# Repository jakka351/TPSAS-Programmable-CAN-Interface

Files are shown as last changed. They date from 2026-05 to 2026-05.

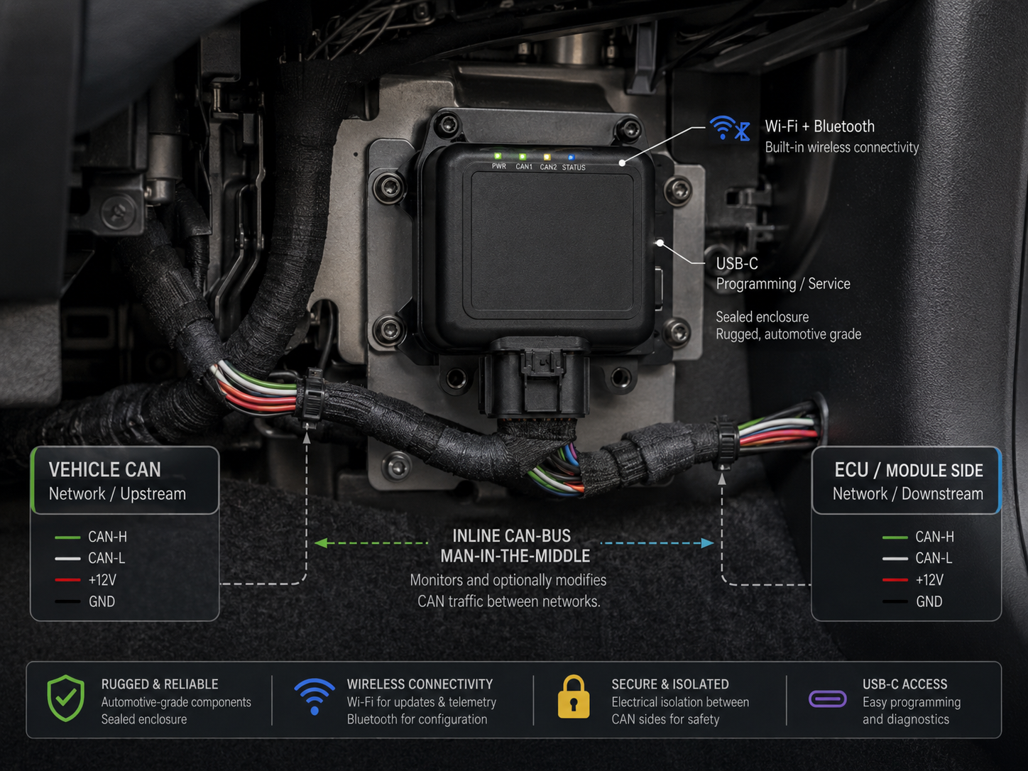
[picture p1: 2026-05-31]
Images/f03ede50-c43b-40d3-97b5-9d50db2d8d2a.png

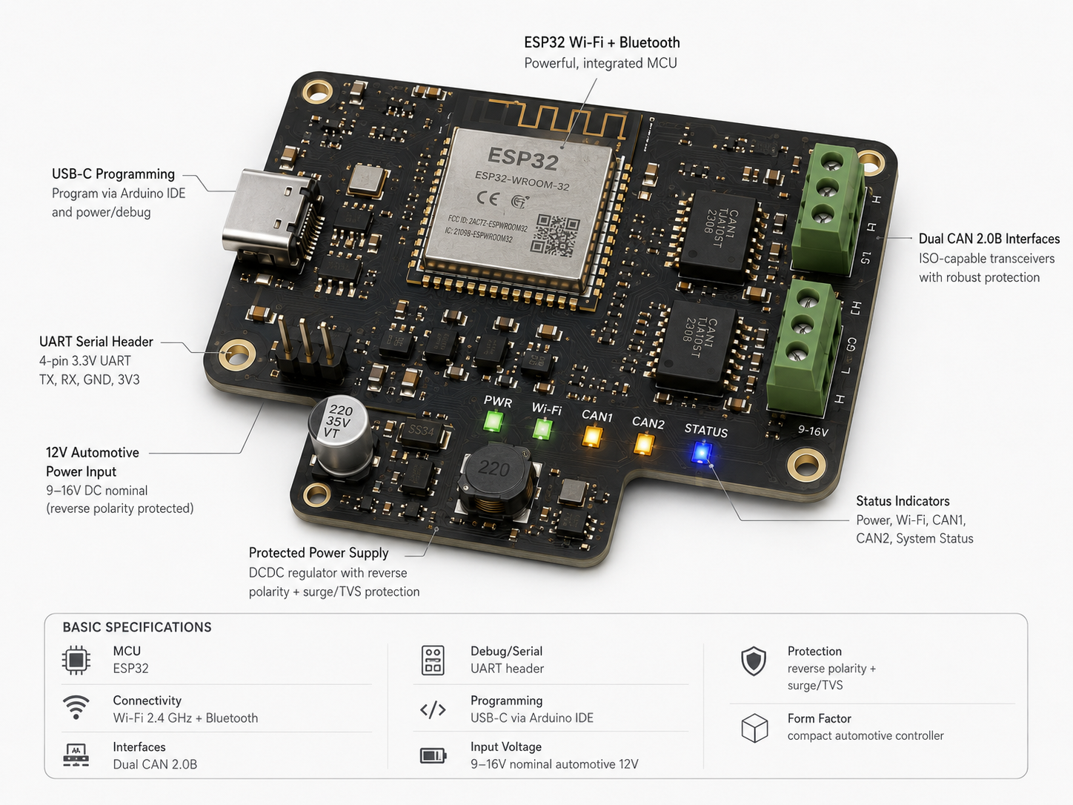
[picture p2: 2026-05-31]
Images/567d3d4d-e929-4fd6-9a81-4a7305392d17.png

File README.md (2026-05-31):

<p align="right"><a href="https://testerpresent.com.au">

</a></p>

# TPSAS-CAN-001
### Tester Present Programmable CAN Interface.


Dual-Isolated CAN Interfaces with Serial UART, Wifi, Bluetooth and USB - Programmable via Arduino IDE or the Tester Present Tool. Available from the releases tab.  

## Firmware Editor and Flash Tool. 
Tester Present developed software for editing firmware, creating a firmware image and flashing it to the device.  
  


## Firmware
Base firmware for the device, to which a customer layer can be added specifying custom behaviour.

***



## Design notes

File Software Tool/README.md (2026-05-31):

<p align="right"><a href="https://testerpresent.com.au">

</a></p>

# TP-CAN-2I Configurator

Windows PC configurator for the **TP-CAN-2I Programmable Dual-CAN Inline Interface**
by *Tester Present Specialist Automotive Solutions*.

It reads, writes, backs up, and flashes the device's firmware/config over **three
transports**, all speaking the same transport-agnostic **TP-DPP v1.0** application
protocol (`Docs/Device_Programming_Protocol.md`):



| Transport | How |
|---|---|
| **J2534 (CAN)** | SAE J2534 PassThru, ISO 15765-2 (ISO-TP) @ 500 kbit/s, tool-TX `0x7FE` / device-RX `0x7FA`. Reuses the existing `J2534` stack. |
| **Serial UART** | COM port @ 921600 8N1, framed `54 50 | LEN(2 BE) | PDU | CRC16-CCITT(2 BE)` with magic resync. |
| **USB-C** | The ESP32-S3 native USB CDC virtual COM port — same serial framing. |

## Features

- **Firmware editor** — IDE-style syntax-highlighting code editor (C/C++/Arduino),
  Consolas font, light theme, line-number gutter, debounced re-highlighting. New /
  Open / Save and a **Build (.bin)** button that shells out to `arduino-cli`.
- **Flash tab** — load a `.bin` or Intel `.hex`, **Read / Backup from device**, and
  **Write + Verify + Activate** with a live progress bar + log, following the §6
  canonical flashing sequence (session → erase → request-download → transfer loop →
  transfer-exit → CRC verify → activate → reset).
- **Console tab** — live transport log + CAN/serial frame traffic.
- **Connection panel** — transport / device (J2534 devices or COM ports) / baud,
  Connect / Disconnect, and a read-only identity readout (app version, serial,
  partition map, running OTA slot).

## Build

Requires the **.NET Framework 4.8.1** targeting pack (the .NET SDK 9 toolchain on
this machine already has it). From the repository root:

```
dotnet build Software/TPCANConfigurator/TPCANConfigurator.csproj -c Release
```

The output `TPCANConfigurator.exe` lands in
`Software/TPCANConfigurator/bin/Release/net481/`.

### Opening in Visual Studio

Open `Software/TPCANConfigurator/TPCANConfigurator.csproj` directly (it's an
SDK-style project). The entire UI is built in code — there is **no** `.Designer.cs`
and **no** `.resx`, so the WinForms designer is intentionally not used (this avoids
designer/resx build pitfalls). Edit `MainForm.cs` and run.

## Project layout

```
TPCANConfigurator/
  TPCANConfigurator.csproj   SDK-style net481 WinForms; includes ..\J2534\**\*.cs
  Program.cs                 [STAThread] entry point
  MainForm.cs                Whole UI (menu, toolbar, panels, tabs, status bar)
  Dpp/
    ITransport.cs            Transport abstraction
    J2534Transport.cs        CAN via J2534Manager (0x7FE/0x7FA)
    SerialTransport.cs       Serial + USB-C (54 50 | LEN | PDU | CRC16 framing)
    DppClient.cs             All TP-DPP services, DIDs, routines, §6 flash flow
    Crc.cs                   CRC-16/CCITT-FALSE + CRC-32/IEEE
  Fw/
    IntelHex.cs              Intel .hex -> byte[]
    FirmwareImage.cs         .bin / .hex loader (bytes + CRC32 + size)
  Editor/
    CodeEditor.cs            RichTextBox + gutter syntax editor
  Compat/
    ELM327Transport.cs       Compile-time stub for a J2534-stack dependency (see note)
```

## Transport notes

- **CAN/J2534**: the adapter does ISO-TP segmentation/reassembly, so the PC side is
  just `J2534Manager.SendReceive(0x7FE, pdu)`. Pick a J2534 device in the Connection
  panel (enumerated from the registry via `J2534DeviceFinder`).
- **Serial / USB-C**: pick a COM port. Baud defaults to 921600 (ignored by USB-CDC,
  honoured by the UART header). The framing layer handles CRC validation and magic
  resync automatically.
- **responsePending (NRC 0x78)**: long operations (erase / write / verify) are
  handled by waiting up to **P2\*** (default 5000 ms, refined from the session
  control response).

## arduino-cli requirement (Build feature)

The editor's **Build (.bin)** button compiles the open sketch by shelling out to
[`arduino-cli`](https://arduino.github.io/arduino-cli/). It is **not bundled**. If it
isn't found on `PATH` (or at the path entered in the *arduino-cli:* box), the app
shows install guidance instead of failing silently:

1. Download `arduino-cli` and put `arduino-cli.exe` on your `PATH`.
2. Install the ESP32 core: `arduino-cli core install esp32:esp32`.
3. Click **Build** — output `.bin` lands in the sketch's `build/` folder
   (`--fqbn esp32:esp32:esp32s3`).

## Note on the J2534 stack

The reused `Software/J2534/*` sources reference an `ELM327Transport` class whose
definition was **not** shipped with those three files. To build without modifying the
read-only J2534 sources, a minimal compile-time stub lives in
`Compat/ELM327Transport.cs`. The Configurator never selects an ELM327 adapter (it
uses J2534 PassThru / Serial / USB-C), so that code path is never exercised.

---

© 2026 Jack Leighton — Designed in Australia

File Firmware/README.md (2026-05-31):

# TP-CAN-2I — ESP32-S3 Firmware (`TesterPresent_CAN_Interface`)

**Tester Present Specialist Automotive Solutions** · © 2026 Jack Leighton · Designed in Australia

Production Arduino firmware for the **TP-CAN-2I Programmable Dual-CAN Inline Interface** — a rugged
automotive CAN man-in-the-middle (MITM) gateway built on the ESP32-S3-WROOM-1-N16R8 with two
galvanically-isolated MCP2518FD CAN-FD channels. It bridges/filters/rewrites CAN traffic between a
vehicle harness (CAN1/upstream) and an ECU/module (CAN2/downstream), and is field-programmable over
**CAN (J2534 ISO-TP)**, **USB-C CDC**, and **UART** using the Tester Present Device Programming
Protocol (TP-DPP), defined in [`../../Docs/Device_Programming_Protocol.md`](../../Docs/Device_Programming_Protocol.md).

---

## 1. Files

| File | Role |
|---|---|
| `TesterPresent_CAN_Interface.ino` | `setup()`/`loop()`: init, MITM bridge, transport→DPP dispatch, LEDs, OTA rollback confirm |
| `config.h` | Pin map, CAN IDs (0x7FE/0x7FA), firmware version + build date, feature flags, default config blob layout |
| `dpp.h` / `dpp.cpp` | Transport-agnostic TP-DPP engine: all services, DIDs, routines, OTA (esp_ota), config blob (NVS), CRC16/CRC32 |
| `isotp.h` / `isotp.cpp` | Minimal ISO 15765-2 (ISO-TP) over one classic-CAN channel (RX 0x7FE / TX 0x7FA) |
| `mcp2518fd.h` / `mcp2518fd.cpp` | Compact self-contained MCP2518FD SPI driver (two instances, shared FSPI bus) |
| `transports.h` / `transports.cpp` | USB-CDC + UART1 `TP`-framing (CRC16-CCITT, magic-resync) + CAN/ISO-TP glue; uniform `getPdu()`/`sendPdu()` |
| `mitm.h` / `mitm.cpp` | CAN1↔CAN2 bridge with per-frame rule hook honouring `mitm_mode` (passthru/filter/rewrite/block) |

---

## 2. GPIO Pin Map (ESP32-S3-WROOM-1-N16R8)

Matches [`../../Hardware/Schematic_Design.md`](../../Hardware/Schematic_Design.md) (Block 6/8) and the
Engineering Specification §5. Strapping-safe choices; the N16R8 octal-PSRAM pins (GPIO26–37) are left
untouched.

| Function | GPIO | Dir | Connected to |
|---|---:|:--:|---|
| USB D− | 19 | — | native USB CDC (fixed by silicon) |
| USB D+ | 20 | — | native USB CDC (fixed by silicon) |
| SPI2/FSPI SCK | 12 | OUT | both MCP2518FD SCK |
| SPI2/FSPI MOSI (SDI) | 11 | OUT | both MCP2518FD SDI |
| SPI2/FSPI MISO (SDO) | 13 | IN | both MCP2518FD SDO |
| CAN1 CS (U7) | 10 | OUT | MCP2518FD #1 nCS (10k pull-up) |
| CAN2 CS (U8) | 14 | OUT | MCP2518FD #2 nCS (10k pull-up) |
| CAN1 INT (U7) | 4 | IN | MCP2518FD #1 nINT (active-low) |
| CAN2 INT (U8) | 5 | IN | MCP2518FD #2 nINT (active-low) |
| UART1 TX | 17 | OUT | DT pin 10 + service header J3 |
| UART1 RX | 18 | IN | DT pin 11 + service header J3 |
| IGN / WAKE sense | 16 | IN | R2/R3 divider off DT pin 3 (RTC-capable) |
| LED Wi-Fi (blue, LED2) | 38 | OUT | → 1k → LED → GND |
| LED CAN1 (amber, LED3) | 39 | OUT | → 1k → LED → GND |
| LED CAN2 (amber, LED4) | 40 | OUT | → 1k → LED → GND |
| LED STATUS (blue, LED5) | 41 | OUT | → 1k → LED → GND |
| LED PWR (green, LED1) | — | — | hard-wired 3V3 → 1k → LED → GND |
| BOOT (SW1) | 0 | IN | strapping; tactile to GND |
| RESET (SW2) | EN | — | chip EN; tactile to GND |

- **SPI:** 10 MHz SCK, MODE0. **Oscillator:** 40 MHz on CLKIN of U7; U7 CLKO daisy-chains U8.
- **Reserved — do not use:** GPIO 26–37 (flash + octal PSRAM). **Avoid as outputs:** 0, 3, 45, 46.

---

## 3. Library Dependencies

The firmware uses **only the Arduino-ESP32 core** — no third-party CAN library is required (the
MCP2518FD driver is self-contained in `mcp2518fd.cpp`). Core components used:

- `SPI` (FSPI bus to the controllers)
- `WiFi` (lightweight SoftAP bring-up; off by default)
- `Preferences` (NVS storage for the config blob + programming-bus select)
- `esp_ota_ops` / `esp_partition` / `esp_system` / `esp_mac` (OTA to the inactive slot, rollback,
  identity) — all bundled with the ESP-IDF inside the Arduino-ESP32 core.

### Install (Arduino IDE — Boards Manager)
1. **File → Preferences → Additional boards manager URLs**, add:
   `https://espressif.github.io/arduino-esp32/package_esp32_index.json`
2. **Tools → Board → Boards Manager…**, install **“esp32” by Espressif Systems** (v3.0.0 or newer,
   which is ESP-IDF v5.x; the OTA/partition API names used here match that line).

### Install (arduino-cli)
```bash
arduino-cli config add board_manager.additional_urls https://espressif.github.io/arduino-esp32/package_esp32_index.json
arduino-cli core update-index
arduino-cli core install esp32:esp32
# Compile (OTA-capable 16 MB partition scheme; see below):
arduino-cli compile --fqbn "esp32:esp32:esp32s3:USBMode=hwcdc,CDCOnBoot=cdc,FlashSize=16M,PartitionScheme=app5M_fat24M_16MB,PSRAM=opi" Firmware/TesterPresent_CAN_Interface
# Upload:
arduino-cli upload -p COMx --fqbn "esp32:esp32:esp32s3:USBMode=hwcdc,CDCOnBoot=cdc,FlashSize=16M,PartitionScheme=app5M_fat24M_16MB,PSRAM=opi" Firmware/TesterPresent_CAN_Interface
```

> Any partition scheme that provides **two app/OTA slots + an NVS partition** works. The default
> `Minimal SPIFFS (1.9MB APP with OTA/190KB SPIFFS)` also has dual OTA but is too small for a 16 MB
> board; prefer a 16 MB OTA layout. If you need a larger single app, generate a custom `partitions.csv`
> with `ota_0`, `ota_1`, `otadata`, and `nvs` and select **“Custom”**.

---

## 4. Arduino IDE Build Settings (Tools menu)

| Setting | Value |
|---|---|
| **Board** | ESP32S3 Dev Module |
| **USB CDC On Boot** | **Enabled** (the configurator + DPP serial transport use the native CDC port) |
| **USB Mode** | Hardware CDC and JTAG |
| **Upload Mode** | UART0 / Hardware CDC |
| **Flash Size** | **16MB (128Mb)** |
| **PSRAM** | OPI PSRAM (N16R8 has 8 MB octal PSRAM) |
| **Partition Scheme** | An **OTA-capable** scheme with **two app slots + NVS** (e.g. *16M Flash (3MB APP/9.9MB FATFS)* or a custom dual-OTA 16 MB CSV) |
| **CPU Frequency** | 240 MHz |
| **Core Debug Level** | None (or Error) |

Manual flashing: hold **BOOT (SW1)**, tap **RST (SW2)**, release BOOT (native USB also supports
auto-reset). After the first successful boot the firmware calls `esp_ota_mark_app_valid_cancel_rollback()`
(~5 s in) so a freshly-flashed OTA image is confirmed and the bootloader will not roll it back.

---

## 5. Feature Flags (`config.h`)

| Macro | Default | Meaning |
|---|---|---|
| `DPP_SECURITY` | `0` | SECURITY_ACCESS (0x27) open: seed = 0, any key accepted. Set `1` for a real seed/key + to gate REQUEST_DOWNLOAD. |
| `CANFD_ENABLE` | `0` | Both channels classic CAN 2.0B @ 500k. Set `1` to honour the config blob’s FD-enable/data-bitrate. |
| `WIFI_ENABLE` | `0` | `0` = radios off (lowest quiescent). `1` = quiet SoftAP `TP-CAN-2I-XXXX` + Wi-Fi LED on. |
| `BLE_ENABLE` | `0` | Reserved for a future field-config build. |

---

## 6. Mapping to the Device Programming Protocol

The byte layouts in `dpp.cpp` follow [`../../Docs/Device_Programming_Protocol.md`](../../Docs/Device_Programming_Protocol.md)
exactly. Quick map:

| TP-DPP item | Where implemented |
|---|---|
| Serial framing `54 50 | LEN | PDU | CRC16` + magic-resync (§2.2/2.3) | `transports.cpp` `sendSerial()` / `pumpSerial()` |
| CAN ISO-TP RX 0x7FE / TX 0x7FA, FRAME_PAD 0xAA (§2.1) | `isotp.cpp` |
| Application PDU + positive/negative responses (§3) | `dpp.cpp` `mkPositive()` / `mkNegative()` |
| Services 0x10/0x11/0x22/0x23/0x27/0x2E/0x31/0x34/0x36/0x37/0x3E (§4) | `dpp.cpp` `svc*()` + `dispatch()` |
| DIDs 0xF180/F181/F18A/F190/F1A0/F1B0/0x0100/0x0103 (§4.1) | `dpp.cpp` `readDidPayload()` / `svcWriteDid()` |
| Routines 0xFF01 erase / 0xFF02 verify / 0xFF03 activate / 0x0202 self-test (§4.2) | `dpp.cpp` `svcRoutine()` |
| NRCs incl. 0x78 responsePending for long ops (§5) | `dpp.cpp` NRC macros + `sendResponsePending()` |
| Flashing sequence 1–9, OTA to inactive slot + CRC32 verify + activate + rollback (§6) | `dpp.cpp` `otaBegin/Write/Finalize/Activate` + `markAppValid()` |
| Timing P2 = 50 ms, P2* = 5000 ms, S3 = 2000 ms (§7) | `config.h` `DPP_P2_MS` / `DPP_P2_STAR_MS` / `DPP_S3_MS` |
| Config blob 35-byte layout + CRC16 (§8) | `config.h` `CFG_OFF_*` + `dpp.cpp` `loadDefaultConfig()` / `validateConfig()` |

**Programming bus.** ISO-TP listens on **CAN1** by default; writing DID `0x0103 = 1` switches it to
**CAN2** at runtime (persisted to NVS, ISO-TP re-bound immediately). The MITM bridge never forwards
the DPP request ID (0x7FE) across the barrier on the active programming bus.

**OTA safety.** Firmware is streamed to the **inactive** OTA slot via `esp_ota_write`, validated at
`esp_ota_end` (no boot change), CRC32-verified by routine 0xFF02 against the image on flash, and only
then made bootable by routine 0xFF03 (`esp_ota_set_boot_partition`). The first boot of a new image runs
in `PENDING_VERIFY`; if it never self-confirms it is rolled back automatically.

---

## 7. Runtime behaviour (LEDs)

| LED | Behaviour |
|---|---|
| PWR (green) | On whenever 3V3 is present (hard-wired). |
| Wi-Fi (blue) | On when SoftAP is up (`WIFI_ENABLE=1`), else off. |
| CAN1 (amber) | Blinks on vehicle-side bus traffic. |
| CAN2 (amber) | Blinks on ECU-side bus traffic. |
| STATUS (blue) | Solid after both controllers init OK; ~1 Hz heartbeat while idle/alive. |

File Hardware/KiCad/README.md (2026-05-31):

# TP-CAN-2I — KiCad Project

This folder is the editable PCB source. Because the board cannot be auto-routed blind, it is
delivered as a **validated 4-layer mechanical starting board** plus the complete electrical
definition needed to finish it in KiCad 7/8.

## Files
| File | What it is |
|---|---|
| `TP-CAN-2I.kicad_pcb` | 4-layer board: enclosure-matched outline, M3 mounting holes, **isolation slots**, stackup, branding, and **labelled placement guides** (Dwgs.User). Generated + self-validated (round-trips through the parser). |
| `TP-CAN-2I.kicad_pro` | Project: design rules, **net classes** (Power / CAN_LOGIC / CAN1_ISO / CAN2_ISO) and net-class auto-assign patterns. |
| `TP-CAN-2I.kicad_dru` | Custom DRC rules enforcing **≥4 mm isolation creepage**. |
| `generate_board.py` | Regenerates the mechanical board (needs `pip install kiutils`). Edit dimensions/placement here. |

## Finish workflow (in KiCad)
1. **Open** `TP-CAN-2I.kicad_pro`. The PCB opens with the outline, holes, slots, and a
   placement guide rectangle + label for every major block (matches `../BOM.csv` ref-des).
2. **Schematic capture:** create `TP-CAN-2I.kicad_sch` and enter the design from
   [`../Schematic_Design.md`](../Schematic_Design.md) (net-by-net, by pin name). Assign each
   symbol the **Footprint** listed in [`../BOM.csv`](../BOM.csv).
3. **Update PCB from schematic** (F8). Components land; drag each onto its labelled guide.
4. **Route** per [`../Fabrication_Notes.md`](../Fabrication_Notes.md):
   ground plane on In1.Cu, power on In2.Cu, CAN pairs coupled, tight buck hot-loop, and
   **nothing crossing the isolation barrier** (the DRC rules will flag violations).
5. **DRC** → fix → **export** Gerbers/drill/CPL to `../Production` (see fab checklist).

## Why it's built this way
KiCad is not installed in the authoring environment, so a hand-routed board could not be
verified. Everything that *can* be made exact and machine-checked — outline, stackup, layers,
mounting, isolation slots, net classes, DRC rules, BOM, and the full net list — is provided
and validated. The remaining step (symbol placement + copper routing) is interactive work that
belongs in KiCad with a human confirming the isolation layout on-screen.

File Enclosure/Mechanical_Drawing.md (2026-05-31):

# TP-CAN-2I — Enclosure Mechanical Drawing

**Model:** TP-CAN-2I Programmable Dual-CAN Inline Interface · **Rev A** · units **mm**
© 2026 Jack Leighton — Tester Present Specialist Automotive Solutions · Designed in Australia

Two-part rugged sealed enclosure (base tray + lid). Manufacturing master is the pair of
2-manifold STL meshes in [`STL/`](STL); this sheet dimensions them for quoting, fixturing and
incoming inspection. Parametric source: [`build_enclosure.py`](build_enclosure.py) (authoritative)
and [`TP-CAN-2I_enclosure.scad`](TP-CAN-2I_enclosure.scad) (OpenSCAD reference).

Previews: [base](STL/preview_base.png) · [lid](STL/preview_lid.png) · [assembly](STL/preview_assembly.png)

---

## 1. Overall envelope

| Dimension | Value |
|---|---|
| Body footprint (excl. ears) | **80.0 × 60.0** |
| Mounting footprint (incl. ears) | **112.4 × 72.8** |
| Base height (floor underside → rim) | **24.6** |
| Lid thickness (plate) | **3.0** |
| Assembled height (ear feet → lid top) | **28.4** |
| Wall thickness | **3.0** |
| Floor / lid thickness | **3.0 / 3.0** |
| Outer vertical corner radius | **4.0** |
| Internal usable cavity (W×D×H) | 74 × 54 × 21.6 |
| Est. printed mass (Tough resin, both parts) | ~95 g |

Coordinate origin = lower-left outer corner of the body, +Z up. The PCB cavity lower-left inner
corner is at (3, 3); the **PCB origin** is (5, 5) and the board is 70 × 50.

---

## 2. Base — top view (looking down −Z)

```
            Y
            ▲   ◄──────────────── 80.0 ────────────────►
            │   ╭───────────────────────────────────────╮
   (-9.2,69.2)●  │  ╭(5.5,54.5)              (74.5,54.5)╮ │  ●(89.2,69.2)
        M5 ⌀5.5  │  ○ tower            LED row →         ○ │   M5 ⌀5.5
            │ ╱  │     ┌───────────────────────────────┐   │ ╲
         60.0    │     │   ◦(9,51)            (71,51)◦  │   │
            │    │     │      PCB standoffs  ⌀6.5       │   │  ┌── connector
            │    │     │      M3 insert ⌀4.0 × 4        │   │  │   aperture
            │    │     │                               │   │  ▼   (on +X wall)
            │    │     │   ◦(9,9)             (71,9)◦   │   │ ████  25.0(Y) × 15.0(Z)
   (-9.2,-9.2)●  │  ○(5.5,5.5)              (74.5,5.5)○ │ │  ●(89.2,-9.2)
        M5 ⌀5.5  │  ╰─────────────────────────────────╯ │   M5 ⌀5.5
            │   ╰────────────────█████────────────────────╯
            │        USB-C port ▲ 13.0(X) × 8.0(Z)  (on −Y wall, ctr X=11)
            └───────────────────────────────────────────────────► X
```

**PCB mounting (M3):** 4 × Ø4.0 heat-set insert pilots at **(9,9) (71,9) (9,51) (71,51)** —
pattern **62 × 42**, standoff Ø6.5 × 4.0 tall (PCB seats at Z=7.0).
**Lid-screw towers (M3):** 4 × Ø4.0 insert pilots at **(5.5,5.5) (74.5,5.5) (5.5,54.5) (74.5,54.5)**,
tops flush with rim (Z=24.6).
**Corner ears (M5):** 4 × Ø5.5 thru with Ø10.0 × 3 deep eyelet pocket; centres at
**(−9.2,−9.2) (89.2,−9.2) (−9.2,69.2) (89.2,69.2)** — pattern **98.4 × 78.4**. Ears drop 0.8 below
the floor to act as defined contact feet.

---

## 3. Base — front view (+X end wall, the connector wall)

```
   Z ▲                         80.0 wide (into page = X is depth here; this is the Y–Z face)
     │   ╭──────────────────────────────────────────╮  ◄ rim (Z=24.6)
24.6 │   │  ░░░ gasket groove 1.2w × 1.4d ░░░░░░░░░░ │
     │   │                                          │
21.0 │   │        ┌────────────────────────┐  ▲     │   connector aperture
     │   │   ⊕    │  Deutsch DT-12 window   │  15.0  │   25.0 (Y) × 15.0 (Z)
13.5 │   │ M3⌀3.3 │  25.0 × 15.0            │  ▼     │   flange screws M3 ⌀3.3
     │   │ flange └────────────────────────┘        │   at Y=14.5 & 45.5, Z=13.5
 6.0 │   │  (Y=14.5)        (Y=45.5)                 │   aperture Y 17.5…42.5
     │   │                                          │
 0.0 │   ╰──────────────────────────────────────────╯  ◄ floor underside
     └──────────────────────────────────────────────► Y
         ◄─────────────────── 60.0 ──────────────────►
```

---

## 4. Base — right side view (−Y wall, the USB wall)

```
   Z ▲          ◄──────────────── 80.0 ────────────────►
24.6 │   ╭───────────────────────────────────────────╮  ◄ rim
     │   │░░ gasket groove ░░░░░░░░░░░░░░░░░░░░░░░░░░░ │
12.6 │   │            ┌───────────┐                   │   USB-C service port
 8.6 │   │   PCB ►----│ 13.0×8.0  │  (ctr X=11)       │   13.0 (X) × 8.0 (Z)
 4.6 │   │            └───────────┘                   │   Z 4.6…12.6  (PCB top Z=8.6)
 0.0 │   ╰───────────────────────────────────────────╯
-0.8 │  ▐█▌                                       ▐█▌    ◄ ear feet protrude 0.8
     └───────────────────────────────────────────────► X
```

---

## 5. Lid (printed upside-down: mating face = Z0)

```
   ╭───────────────────────────────────────────╮   80.0 × 60.0 × 3.0 plate, R4 corners
   │ ⊙(5.5,54.5)                    (74.5,54.5)⊙ │   ⊙ = M3 screw: Ø3.4 thru +
   │                                            │       Ø6.2 × 2 counterbore (from top)
   │            ● ● ● ● ●  LED pipes            │
   │            26 31 36 41 46  (Y=48, Ø3.2)    │   5 × Ø3.2 light-pipe holes @ 5 pitch
   │        ┌────────────────────────┐          │
   │        │  recessed label pocket │          │   branding recess 52 × 14 × 0.6 deep
   │        │  "TESTER PRESENT"      │          │       (engrave / printed insert)
   │        └────────────────────────┘          │
   │ ⊙(5.5,5.5)                      (74.5,5.5)⊙ │
   ╰───────────────────────────────────────────╯
   Underside: 4 perimeter registration ribs (tongue) 2.0 wide × 4.0 deep, set 3.2 in from
   the wall, running the mid-span of each edge (clear of corner towers & standoffs).
```

---

## 6. Seal & closure

| Feature | Spec |
|---|---|
| Seal type | Gasket-in-rim + lid registration tongue |
| Gasket groove | width **1.2**, depth **1.4**, centred in the 3.0 rim (0.9–2.1 from outer edge) |
| Recommended gasket | Ø1.5 mm silicone O-cord (continuous loop), or 1.5 mm closed-cell foam tape |
| Lid tongue | 2.0 × 4.0 ribs, 0.2 clearance to inner wall (registration, not the seal face) |
| Closure | 4 × M3 × 10 SHCS, lid → corner-tower heat-set inserts |
| Sealing target | IP65 (dust-tight, low-pressure water jets) with gasket fitted |

---

## 7. Material, process & tolerances

| Item | Spec |
|---|---|
| Primary process | **SLA**, tough/durable resin (Formlabs Tough 2000 or Durable; or Siraya Tech ABS-Like) |
| Production alt. | **SLS PA12 (nylon)** for highest impact/temperature ruggedness |
| General tolerance | ±0.20 (features), ±0.15 (hole Ø) |
| Heat-set inserts | M3 brass, Ø4.0 pilot (e.g., CNC-Kitchen M3×5.7 / McMaster 94180A331) — install with iron |
| Min wall / detail | 1.5 mm honoured throughout; rim lips 0.9 mm (resin-rigid OK) |
| Finish | bead-blast / matte; UV post-cure per resin spec; black or hi-vis safety orange |
| Print orientation | base: floor-down; lid: top-face-down (mating tongue up) — both supported off feet/ribs |

---

## 8. Inspection checklist (first article)

- [ ] Footprint 80.0 × 60.0 ±0.2; assembled height 28.4 ±0.3.
- [ ] M5 ear pattern 98.4 × 78.4; M5 holes Ø5.5 clear, eyelet pockets Ø10.0 × 3.
- [ ] PCB insert pattern 62 × 42; 4 × Ø4.0 inserts seat flush, PCB datum height 7.0.
- [ ] Connector aperture 25.0 × 15.0 at Z 6–21; flange holes Ø3.3 at Y 14.5/45.5.
- [ ] USB-C port 13.0 × 8.0 at Z 4.6–12.6, centred X=11.
- [ ] 5 × LED Ø3.2 at Y=48, X=26/31/36/41/46.
- [ ] Lid closes on towers; gasket groove clean & continuous; tongue clears towers/standoffs.
- [ ] Watertight check (mesh): lid 2-manifold; base closed solid (see `build_enclosure.py` report).
```

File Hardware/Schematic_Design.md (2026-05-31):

# TP-CAN-2I — Schematic Design (Net-by-Net)

Connections are given by **pin name** (unambiguous for schematic capture). Passive feedback /
timing values are nominal starting points — **confirm against the latest device datasheet**
during schematic finalisation. Reference designators match [`BOM.csv`](BOM.csv).

**Net domains**
- **Logic GND** — ESP32-S3, controllers, regulators, USB.
- **GND_ISO1 / +5V_ISO1** — isolated bus domain for CAN1 (vehicle/upstream).
- **GND_ISO2 / +5V_ISO2** — isolated bus domain for CAN2 (ECU/downstream).
- The three grounds connect **only** through the isolation parts (ISO1042B, A0505S).

---

## Block 1 — Power Input & Protection

```
DT pin1 +VBAT ─► F1(3A) ─► [Q1 N-FET + U11 LM74700 ideal-diode] ─► VBAT_PROT
DT pin2 GND   ─────────────────────────────────────────────────► Logic GND
```
- **F1** in series with +VBAT from connector pin 1.
- **U11 LM74700-Q1** ideal-diode controller drives **Q1 (CSD18532 N-FET)** as reverse-polarity
  pass element: VBAT(fused) → Q1 drain; Q1 source → VBAT_PROT. U11 VS=source, VIN(anode)=drain,
  GATE=Q1 gate, GND=Logic GND. (Blocks reverse current, ~ideal forward drop.)
- **D2 SMCJ33A** TVS: VBAT_PROT → Logic GND (clamps load-dump to ≤53 V).
- **L1 (4.7 µH)** + **C1 (100 µF)** + **C2 (2×10 µF)**: π input filter on VBAT_PROT.

## Block 2 — 5 V Pre-Regulator (U1 TPS54360B-Q1)

| Pin | Net | Notes |
|---|---|---|
| VIN | VBAT_PROT | + C2 bypass |
| EN | VBAT_PROT via R12(499k)/R13(75k) divider | programmable UVLO (~6–7 V on) |
| BOOT | → 100 nF → SW | bootstrap cap |
| SW | → L2(22 µH) → +5V; **D6 SS34** cathode→SW, anode→GND | catch diode (non-sync) |
| FB | +5V via R9(52.3k)/R10(10k) to GND | sets 5.0 V (Vref 0.8 V) |
| RT/CLK | → R11(182k) → GND | ~500 kHz |
| COMP | → R-C compensation → GND | per datasheet (e.g. 3.3 nF + 13 k) |
| GND / PAD | Logic GND | thermal pad to GND pour |

Output **+5V** bulk: **C4 47 µF** + 100 nF. Clamp **D5 SMAJ5.0A** on +5V.

## Block 3 — 3.3 V Logic Regulator (U2 TLV62569)

| Pin (name) | Net |
|---|---|
| VIN | +5V |
| EN | +5V (or GPIO for sequencing) |
| SW | → L3(2.2 µH) → +3V3 |
| FB | +3V3 via R14(540k)/R15(120k) to GND (3.3 V, Vref 0.6 V) |
| GND | Logic GND |

Output **+3V3** bulk: **C5 22 µF** + 100 nF. Powers ESP32-S3, both MCP2518FD (VDD),
ISO1042B **logic side** (VCC1), oscillator, LEDs.

## Block 4 — Isolated CAN Bus Supplies (U3, U4 A0505S-1W)

Two independent modules, each: **+5V → +5V_ISOn**.
- U3: VIN=+5V, GND=Logic GND, VOUT=+5V_ISO1, 0V=GND_ISO1. Bulk **C9 10 µF** on +5V_ISO1.
- U4: VIN=+5V, GND=Logic GND, VOUT=+5V_ISO2, 0V=GND_ISO2. Bulk **C9 10 µF** on +5V_ISO2.
- Input bypass 4.7 µF each. Provides galvanic isolation for each transceiver bus side.

## Block 5 — USB-C Power-Path (U5 LM66100)

- USB **VBUS** → U5 (ideal diode) → +5V rail (OR-ing with buck output so either source powers
  logic on the bench without back-feeding the vehicle supply).
- U5 ON pin tied for auto-on; current-limit per datasheet.

---

## Block 6 — MCU (U6 ESP32-S3-WROOM-1-N16R8)

| Module pin | Net | Notes |
|---|---|---|
| 3V3 | +3V3 | + C10 4.7 µF + 100 nF |
| GND (all) | Logic GND | thermal/RF ground |
| EN | +3V3 via R5(10k); SW2 to GND; 1 µF to GND | reset, RC delay |
| IO0 | R5(10k) to +3V3; SW1 to GND | BOOT strap |
| IO19 | USB_DM | native USB D− |
| IO20 | USB_DP | native USB D+ |
| IO12 | SPI_SCK | to both MCP2518FD SCK |
| IO11 | SPI_MOSI | to both MCP2518FD SDI |
| IO13 | SPI_MISO | from both MCP2518FD SDO |
| IO10 | CAN1_CS | MCP2518FD #1 nCS (R6 10k pull-up to 3V3) |
| IO14 | CAN2_CS | MCP2518FD #2 nCS (R6 10k pull-up to 3V3) |
| IO4 | CAN1_INT | MCP2518FD #1 nINT |
| IO5 | CAN2_INT | MCP2518FD #2 nINT |
| IO17 | UART1_TX | to connector pin10 + service header |
| IO18 | UART1_RX | from connector pin11 + service header |
| IO16 | IGN_SENSE | from divider R2(100k)/R3(22k) off DT pin3 + TVS |
| IO38 | LED_WIFI | → R4(1k) → LED2(blue) → GND |
| IO39 | LED_CAN1 | → R4(1k) → LED3(amber) → GND |
| IO40 | LED_CAN2 | → R4(1k) → LED4(amber) → GND |
| IO41 | LED_STATUS | → R4(1k) → LED5(blue) → GND |
| (3V3) | LED_PWR | +3V3 → R4(1k) → LED1(green) → GND (hard-wired) |

**Reserved (do not connect):** IO26–IO37 (flash + octal PSRAM). Avoid driving IO0/IO3/IO45/IO46.

## Block 7 — USB-C (J1) + ESD (D1)

| J1 | Net |
|---|---|
| VBUS | USB VBUS → U5 power-path |
| GND / SHIELD | Logic GND (shield via RC to GND) |
| CC1 | R1(5.1k) → GND |
| CC2 | R1(5.1k) → GND |
| D+ (both) | → D1 USBLC6 → USB_DP → IO20 |
| D− (both) | → D1 USBLC6 → USB_DM → IO19 |

**D1 USBLC6-2SC6**: I/O1=D+, I/O2=D−, VBUS pin→USB VBUS, GND→GND.

---

## Block 8 — CAN Controllers (U7, U8 MCP2518FD)

Shared SPI bus, independent CS/INT. **Clock:** Y1 40 MHz CMOS oscillator → U7 OSC1; U7
**OSC2/CLKO** → U8 OSC1 (daisy-chain). Each VDD=+3V3 + 100 nF; VSS=Logic GND.

| Signal | U7 (CAN1) | U8 (CAN2) |
|---|---|---|
| nCS | CAN1_CS (IO10) | CAN2_CS (IO14) |
| SCK | SPI_SCK | SPI_SCK |
| SDI | SPI_MOSI | SPI_MOSI |
| SDO | SPI_MISO | SPI_MISO |
| nINT | CAN1_INT (IO4) | CAN2_INT (IO5) |
| OSC1 | Y1 40 MHz | U7 CLKO |
| TXCAN | CAN1_TXD → U9 TXD | CAN2_TXD → U10 TXD |
| RXCAN | CAN1_RXD ← U9 RXD | CAN2_RXD ← U10 RXD |
| VDD/VSS | +3V3 / GND | +3V3 / GND |

## Block 9 — Isolated Transceivers (U9, U10 ISO1042B) + Protection

**U9 = CAN1 (vehicle), U10 = CAN2 (ECU).** Logic side from +3V3/Logic GND; bus side from
+5V_ISOn / GND_ISOn.

| ISO1042B pin | CAN1 (U9) | CAN2 (U10) |
|---|---|---|
| VCC1 (logic) | +3V3 + 100 nF | +3V3 + 100 nF |
| GND1 | Logic GND | Logic GND |
| TXD | CAN1_TXD | CAN2_TXD |
| RXD | CAN1_RXD | CAN2_RXD |
| VCC2 (bus) | +5V_ISO1 + 100 nF + C9 10 µF | +5V_ISO2 + … |
| GND2 | GND_ISO1 | GND_ISO2 |
| CANH | → CMC1 → CAN1H_raw | → CMC2 → CAN2H_raw |
| CANL | → CMC1 → CAN1L_raw | → CMC2 → CAN2L_raw |

**Per-channel bus network (after the common-mode choke CMCn):**
- **Split termination:** R7(60 Ω) CANH→TERMn, R7(60 Ω) TERMn→CANL, **C7 4.7 nF** TERMn→GND_ISOn.
- **Selectable 120 Ω:** R8(120 Ω) across CANH/CANL via jumper J4 (CAN1) / J5 (CAN2).
- **TVS:** D3/D4 **PESD2CAN** CANH/CANL → GND_ISOn.
- CANH/CANL → connector: CAN1→DT pins 4/5, CAN2→DT pins 7/8. GND_ISO1→pin6, GND_ISO2→pin9.

---

## Block 10 — Connectors & Headers

- **J2 Micro-Fit 12-ckt** (internal board header → harness loom): maps 1:1 to the DT 12-way
  pinout in the spec (power, IGN, CAN1 H/L/GND, CAN2 H/L/GND, UART TX/RX/GND).
- **J3 UART service header (1×4):** +3V3, UART1_TX, UART1_RX, Logic GND.
- **J4 / J5:** CAN1 / CAN2 termination select (center = bus, ends = enable 120 Ω / off).

## Block 11 — Ignition / Wake

- DT pin3 (switched +) → R2(100k) → IGN_SENSE node → R3(22k) → GND; TVS to GND; 100 nF.
  IGN_SENSE → ESP32 IO16 (RTC-capable) for deep-sleep wake on ignition.

---

## Net Summary (key)

| Net | Members |
|---|---|
| VBAT_PROT | F1, Q1, U11, D2, L1, C1/C2, U1.VIN |
| +5V | U1 out, U2.VIN, U3.VIN, U4.VIN, U5 out, C4 |
| +3V3 | U2 out, U6.3V3, U7/U8.VDD, U9/U10.VCC1, Y1, LEDs, C5/C10 |
| +5V_ISO1 / GND_ISO1 | U3 out, U9.VCC2/GND2, C9 |
| +5V_ISO2 / GND_ISO2 | U4 out, U10.VCC2/GND2, C9 |
| SPI_SCK/MOSI/MISO | U6 ↔ U7,U8 |
| CAN1_TXD/RXD | U7 ↔ U9 |
| CAN2_TXD/RXD | U8 ↔ U10 |
| CAN1H/L | U9 → CMC1 → term/TVS → DT 4/5 |
| CAN2H/L | U10 → CMC2 → term/TVS → DT 7/8 |

> Isolation barrier runs between {GND1/VCC1/TXD/RXD} and {GND2/VCC2/CANH/CANL} of each
> ISO1042B, and across each A0505S. PCB: route **no** copper across the barrier; mill slots.

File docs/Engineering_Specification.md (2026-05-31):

# Tester Present — Programmable CAN Interface
## Master Engineering Specification

| | |
|---|---|
| **Product** | Programmable Dual-CAN Inline Interface (CAN / Serial / USB / Wireless) |
| **Model** | TP-CAN-2I (Tester Present Specialist Automotive Solutions) |
| **Document** | Master Engineering Specification |
| **Revision** | A (2026-05-31) |
| **Author** | Jack Leighton — Tester Present Specialist Automotive Solutions |
| **Copyright** | © 2026 Jack Leighton. All rights reserved. |
| **Origin** | Designed in Australia |

---

## 1. Product Overview

The TP-CAN-2I is a ruggedised, automotive-grade **inline CAN-bus interface** that installs
between a vehicle harness (upstream) and an ECU/module (downstream). It can **monitor,
pass-through, filter, and optionally rewrite** CAN traffic flowing between the two network
segments — a configurable "man-in-the-middle" for diagnostics, emulation, data-logging,
gateway/translation, and bench development.

It is built around an **ESP32-S3** providing Wi-Fi (telemetry / OTA) and Bluetooth LE
(configuration), with **two fully galvanically-isolated CAN FD channels**, a 3.3 V UART
service port, and native USB-C for programming via the Arduino IDE or the Tester Present
Windows configurator.

### 1.1 Primary Use Cases
- Inline CAN man-in-the-middle (intercept / modify / inject between vehicle and module)
- Dual-bus gateway / protocol translation (CAN-A ↔ CAN-B, different bit-rates)
- High-rate CAN/CAN-FD data logger with wireless off-load
- ECU emulation / residual-bus simulation on a bench
- Field reflash / configuration tool (talks to a target over CAN via J2534)

### 1.2 Design Pillars (from product brief & concept renders)
1. **Rugged & reliable** — automotive-grade components, sealed enclosure, heavy-duty connector.
2. **Wireless** — Wi-Fi for updates & telemetry, Bluetooth LE for configuration.
3. **Secure & isolated** — galvanic isolation between the two CAN sides for safety.
4. **Easy access** — USB-C programming and diagnostics; Arduino-IDE compatible.

---

## 2. Key Specifications

| Parameter | Specification |
|---|---|
| **MCU** | Espressif ESP32-S3-WROOM-1-N16R8 (dual-core LX7 @ 240 MHz, 16 MB flash, 8 MB PSRAM) |
| **Wireless** | Wi-Fi 802.11 b/g/n 2.4 GHz + Bluetooth 5 LE (on-module PCB antenna) |
| **CAN channels** | 2 × independent, **galvanically isolated** CAN FD (ISO 11898-2) |
| **CAN controller** | 2 × Microchip MCP2518FD (external SPI controllers, 40 MHz) |
| **CAN transceiver** | 2 × TI ISO1042B isolated FD transceiver (±70 V bus fault, 5 Mbit/s) |
| **CAN bit-rates** | Classic CAN 2.0B 125 k–1 Mbit/s; CAN FD arbitration ≤1 Mbit/s, data ≤5 Mbit/s |
| **CAN isolation** | ≥3 kV<sub>RMS</sub> channel-to-logic and channel-to-channel (reinforced option 5 kV<sub>RMS</sub>) |
| **Serial** | 1 × 3.3 V UART (TX/RX) on connector + internal service header |
| **USB** | USB-C 2.0 Full-Speed, native (ESP32-S3 USB-OTG), ESD protected |
| **Programming** | (a) USB-C + Arduino IDE; (b) Tester Present app over USB-serial; (c) over CAN via J2534; (d) over UART serial |
| **Input voltage** | **9–32 V DC nominal** (supports both 12 V and 24 V systems); survives load-dump transients (clamped 53 V) |
| **Input protection** | Fuse + reverse-polarity (ideal-diode) + TVS (ISO 7637-2 pulse tolerant) + π-filter |
| **Quiescent / sleep** | < 200 µA in deep-sleep (ignition-wake), typical run ≈ 0.6–1.4 W |
| **Indicators** | 5 × LED: PWR, Wi-Fi, CAN1, CAN2, STATUS |
| **Connector** | Deutsch **DT** series, **12-way**, sealed (IP67-mated), 13 A/contact |
| **Enclosure** | Sealed black SLA/ABS-like, IP65 target, 4 × heavy-duty mounting ears (brass inserts) |
| **Operating temp** | −40 °C … +85 °C (component-rated); enclosure −20 °C … +70 °C |
| **PCB** | 4-layer FR-4, 1.6 mm, ENIG, isolation slots between CAN domains |
| **Dimensions (PCB)** | ≈ 70 × 50 mm (target) |
| **Dimensions (case)** | ≈ 95 × 70 × 32 mm excl. connector & mounting ears |

---

## 3. System Block Diagram

```
                          ┌───────────────────────────────────────────────┐
                          │              TP-CAN-2I  (Logic Domain)         │
                          │                                                │
   USB-C ──[USBLC6 ESD]───┼──► ESP32-S3-WROOM-1-N16R8 ◄── BOOT/RESET btns  │
   (native USB, Arduino)  │      │  │  │  │   (Wi-Fi + BT antenna on module)│
                          │      │  │  │  └── 5× Status LEDs                │
   UART (3v3) ◄───────────┼──────┘  │  └───── UART1 to connector           │
                          │   SPI2  │                                       │
                          │     ┌───┴────┬─────────┐                        │
                          │     ▼        ▼         │                        │
                          │  MCP2518FD MCP2518FD   │  40 MHz osc (CLKO ⮞)   │
                          │   (CAN1)    (CAN2)      │                        │
                          │     │TXD/RXD  │TXD/RXD                          │
   ═══════════ ISOLATION BARRIER ═══════════════════════════════════════   │
                          │     ▼          ▼                                │
                          │  ISO1042B    ISO1042B   ◄── 2× isolated 5V DCDC │
                          │  (iso xcvr)  (iso xcvr)     (A0505S-1W each)     │
                          │  CMC+TVS+    CMC+TVS+                            │
                          │  term       term                                │
                          └───┬───┬──────┬───┬───────────────────────────────┘
                              │   │      │   │
                          CAN1H CAN1L  CAN2H CAN2L
                         (Vehicle/upstream) (ECU/downstream)
                              │   │      │   │
                          ┌───┴───┴──────┴───┴───────────────────────┐
   9–32V ──[Fuse]──[Ideal │  Deutsch DT 12-way heavy-duty connector  │
   diode rev-prot]──[TVS]─┤  + power + ignition/wake + UART          │
            │             └──────────────────────────────────────────┘
            ▼
      TPS54360B-Q1 (Vin→5V/3.5A, 60V) ──► TLV62569 (5V→3.3V/2A) ──► 3V3 logic
            └──► 5V rail ──► 2× isolated DCDC (CAN side) , USB power-path OR
```

---

## 4. Electrical Architecture

### 4.1 Power Tree (12 V / 24 V capable)

| Stage | Part | Function |
|---|---|---|
| Input fuse | 3 A slow-blow (1206 / Nano2) | over-current / fault isolation |
| Reverse-polarity | LM74700-Q1 ideal-diode ctrl + N-FET (CSD18532) | low-loss reverse protection |
| Transient clamp | SMCJ33A TVS (uni) + π-filter (ferrite + bulk caps) | ISO 7637-2 load-dump / surge |
| Pre-regulator | **TPS54360B-Q1** (4.5–60 V in, 3.5 A) → **5.0 V** | wide-Vin buck, survives 24 V load-dump |
| Logic regulator | **TLV62569** (5 V → **3.3 V**, 2 A) | ESP32-S3 + controllers + logic |
| CAN1 bus supply | **A0505S-1W** isolated DCDC (5 V→5 V iso) | ISO1042B VCC2, isolated domain 1 |
| CAN2 bus supply | **A0505S-1W** isolated DCDC (5 V→5 V iso) | ISO1042B VCC2, isolated domain 2 |
| USB power-path | LM66100 ideal diode (USB 5 V ⟶ 5 V rail) | bench-power from USB without back-feed |

**Rail budget (typical):** 3.3 V @ ≤500 mA (ESP32 Wi-Fi bursts) + controllers/LEDs ≈ 150 mA;
5 V rail feeds 2× 1 W isolated converters (≈ 200 mA each in) + USB. Pre-reg sized 3.5 A for margin.

### 4.2 Microcontroller
- **ESP32-S3-WROOM-1-N16R8**: native USB-OTG (no USB-UART bridge required), dual-core,
  16 MB flash / 8 MB PSRAM for large MITM buffers and OTA dual-bank.
- Octal-PSRAM variant occupies GPIO33–37 internally — **those GPIO are reserved, do not use.**
- Antenna keep-out per module datasheet must overhang the PCB edge with no copper beneath.

### 4.3 Dual CAN FD (Isolated)
- Two **MCP2518FD** SPI CAN-FD controllers share **SPI2 (FSPI)** with independent CS + INT.
- One **40 MHz** oscillator clocks controller 1; its **CLKO** output daisy-chains controller 2.
- Each controller's TXD/RXD crosses the isolation barrier through an **ISO1042B** transceiver.
- Each transceiver bus side is powered by its **own isolated 5 V** supply → channel-to-channel
  **and** channel-to-logic galvanic isolation (true MITM safety).
- Bus protection per channel: **common-mode choke** (TDK ACT45B) + **CAN TVS** (PESD2CAN)
  + **split termination** (2 × 60 Ω + 4.7 nF to isolated bus GND) + jumper-selectable 120 Ω.

### 4.4 USB / Programming
- USB-C receptacle (16-pin, with mounting tabs), **CC1/CC2 5.1 kΩ** pull-downs (UFP).
- **USBLC6-2SC6** ESD array on D+/D−.
- Native USB connects to ESP32-S3 GPIO19 (D−) / GPIO20 (D+).
- **BOOT (GPIO0)** + **RESET (EN)** tactiles for manual flashing; auto-reset supported by native USB.

### 4.5 Serial UART
- **UART1** (GPIO17 TX / GPIO18 RX), 3.3 V logic, brought to both the connector and an
  internal 4-pin service header (TX, RX, GND, 3V3).

### 4.6 Status Indicators
| LED | Colour | Driven by | Meaning |
|---|---|---|---|
| PWR | Green | Hard-wired to 3V3 | Power good |
| Wi-Fi | Blue | GPIO38 | Wi-Fi/BT activity |
| CAN1 | Amber | GPIO39 | Vehicle-side bus traffic |
| CAN2 | Amber | GPIO40 | ECU-side bus traffic |
| STATUS | Blue | GPIO41 | System/MITM state (heartbeat/error codes) |

---

## 5. ESP32-S3 Pin Allocation

| Function | GPIO | Notes |
|---|---|---|
| USB D− | 19 | native USB (fixed) |
| USB D+ | 20 | native USB (fixed) |
| SPI2 SCK | 12 | to both MCP2518FD |
| SPI2 MOSI (SDI) | 11 | to both MCP2518FD |
| SPI2 MISO (SDO) | 13 | from both MCP2518FD |
| CAN1 CS | 10 | MCP2518FD #1 chip-select |
| CAN2 CS | 14 | MCP2518FD #2 chip-select |
| CAN1 INT | 4 | MCP2518FD #1 interrupt (input) |
| CAN2 INT | 5 | MCP2518FD #2 interrupt (input) |
| UART1 TX | 17 | 3.3 V serial to connector/header |
| UART1 RX | 18 | 3.3 V serial to connector/header |
| LED Wi-Fi | 38 | |
| LED CAN1 | 39 | |
| LED CAN2 | 40 | |
| LED STATUS | 41 | |
| BOOT | 0 | strapping — tactile to GND |
| Ignition/Wake sense | 16 | via divider+TVS; RTC-capable for deep-sleep wake |
| **Reserved** | 26–37 | SPI flash + **octal PSRAM** (N16R8) — DO NOT USE |
| **Avoid as outputs** | 0, 3, 45, 46 | boot strapping pins |

---

## 6. Heavy-Duty Connector — Deutsch DT 12-Way

External harness connector: **Deutsch DT** series, 12-way, sealed (IP67 mated), 13 A/contact,
14–16 AWG capable. Enclosure-wall flange receptacle → short internal loom → polarised locking
board header (Molex Micro-Fit 3.0, 12-ckt) on the PCB ("ECU-style" serviceable interface).

| Pin | Signal | Domain | Wire (AWG / colour) |
|---|---|---|---|
| 1 | +VBAT (9–32 V power in) | Power | 16 / Red |
| 2 | GND (power / chassis) | Power | 16 / Black |
| 3 | IGN / WAKE (switched +) | Logic | 18 / White |
| 4 | CAN1-H (Vehicle / upstream) | Iso domain 1 | 18 / Yellow (twisted pair) |
| 5 | CAN1-L (Vehicle / upstream) | Iso domain 1 | 18 / Green (twisted pair) |
| 6 | CAN1-GND (vehicle bus ref/shield) | Iso domain 1 | 18 / Bare/Drain |
| 7 | CAN2-H (ECU / downstream) | Iso domain 2 | 18 / Orange (twisted pair) |
| 8 | CAN2-L (ECU / downstream) | Iso domain 2 | 18 / Blue (twisted pair) |
| 9 | CAN2-GND (ECU bus ref/shield) | Iso domain 2 | 18 / Bare/Drain |
| 10 | UART-TX (3.3 V out) | Logic | 22 / Grey |
| 11 | UART-RX (3.3 V in) | Logic | 22 / Violet |
| 12 | UART-GND (logic ref) | Logic | 22 / Brown |

> **Note:** CAN-GND pins (6, 9) reference each isolated transceiver's bus-side ground.
> For a true MITM in a single-chassis vehicle they may be left unterminated or tied to
> local chassis at each node; on a bench they provide the isolated return.

Connector part numbers and the harness build procedure are in
[`/Harness/Connector_and_Harness.md`](../Harness/Connector_and_Harness.md).

---

## 7. Isolation Strategy

- **Logic domain:** ESP32-S3, both MCP2518FD controllers, USB, power regulators, LEDs.
- **Isolated domain 1 (CAN1):** ISO1042B bus side + its isolated 5 V supply.
- **Isolated domain 2 (CAN2):** ISO1042B bus side + its isolated 5 V supply.
- Barrier carried by the ISO1042B reinforced isolation and the isolated DCDC transformers.
- **PCB:** isolation **slots milled** under each ISO1042B and DCDC, ≥ 4 mm creepage logic-to-bus
  and bus-to-bus; no copper, no silkscreen, no traces crossing the barrier except through the
  rated parts. Maintain ≥ 8 mm spacing between the two CAN domains where practical.

---

## 8. Mechanical Envelope

- Two-part sealed enclosure (base + lid) with perimeter **gasket groove** (O-ring cord or
  cured-in-place gasket), IP65 target.
- **4 heavy-duty mounting ears** with **brass heat-set inserts** / steel eyelets for M5 bolts.
- Deutsch DT flange receptacle on one end face; **sealed USB-C service port** (rubber bung)
  on an adjacent face.
- PCB on **4 standoffs/bosses** with M3 brass inserts; 1.5 mm clearance to lid for components.
- **LED light-pipes** (5) through the lid, or a clear window strip.
- Full model + drawing: [`/Enclosure/`](../Enclosure/).

---

## 9. Compliance & Environment (targets)

| Item | Target |
|---|---|
| Conducted transients | ISO 7637-2 pulses 1, 2a, 2b, 3a, 3b (clamped front-end) |
| Supply ranges | ISO 16750-2 (12 V & 24 V systems), load-dump survival |
| ESD | IEC 61000-4-2 ±8 kV contact on exposed I/O & USB |
| CAN PHY | ISO 11898-2:2016 (CAN FD) |
| Ingress | IP65 (enclosure), IP67 (mated connector) |
| RoHS / REACH | Compliant component selection |

---

## 10. Programming & Configuration Interfaces

| Path | Transport | Use | Tool |
|---|---|---|---|
| Firmware flash | USB-C native | Load/replace firmware | **Arduino IDE** (ESP32-S3 board) |
| Firmware flash | USB-C native | Load/replace firmware | Tester Present app (esptool backend) |
| Configuration | USB-serial (CDC) | Set CAN bit-rates, MITM rules, filters, Wi-Fi creds | Tester Present app |
| Configuration | **CAN via J2534** | Program/config over the bus | Tester Present app (J2534 PassThru) |
| Configuration | UART serial | Headless config | Tester Present app / terminal |
| Live / OTA | Wi-Fi | Telemetry, OTA update | Tester Present app / web |
| Config | Bluetooth LE | Mobile/field config | (future) |

The on-the-wire configuration protocol is defined in the firmware and mirrored by the
Windows app — see [`/Firmware`](../Firmware/) and [`/Software`](../Software/).

---

## 11. Deliverables Map

| Folder | Contents |
|---|---|
| `/Docs` | This spec, datasheet, design notes |
| `/Hardware/KiCad` | KiCad project (schematic, PCB, netlist) |
| `/Hardware` | `BOM.csv`, fabrication notes |
| `/Enclosure` | OpenSCAD case (base + lid), STL output, drawing |
| `/Harness` | Deutsch DT pinout + harness build document |
| `/Firmware` | ESP32-S3 Arduino firmware |
| `/Software` | .NET 4.8.1 WinForms configurator (J2534 + serial) |

---
*Tester Present Specialist Automotive Solutions — Designed in Australia — © 2026 Jack Leighton.*

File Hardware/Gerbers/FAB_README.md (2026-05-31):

# TP-CAN-2I - Fabrication Gerber Package (REAL COPPER)

Generated by `generate_pcb.py`. Unlike the earlier mechanical-only set, these
layers contain **real copper**: every component land pattern is flashed, the
four copper layers carry pours/planes and routing, solder mask and paste are
matched to the pads, and the drill files are populated.

## Board
| Parameter | Value |
|---|---|
| Size | 70.0 x 50.0 mm, R3 corners |
| Layers | 4 (Sig / GND / PWR / GND) |
| Thickness | 1.6 mm, FR-4 Tg>=150 |
| Copper | 1 oz outer / 0.5 oz inner |
| Finish | ENIG |
| Mask / Silk | Matte black / white |
| Min track/gap | 0.25 / 0.20 mm |
| Via | 0.3 mm drill / 0.6 mm pad |

## What is in this package
- **F_Cu**: 423 flashes - SMD + THT land patterns, via lands, and routed
  power tree, SPI2 bus, CAN TXD/RXD, isolated CAN_H/CAN_L pairs, USB pair, UART.
- **In1_Cu (GND)** and **B_Cu (GND)**: split into three galvanically isolated
  ground domains - LOGIC | CAN1-ISO | CAN2-ISO - with the pours pulled back
  >4 mm around the x=54 mm barrier and the two milled isolation slots.
- **In2_Cu (PWR)**: +3V3 / +5V logic rails plus the two isolated +5V_ISO pours.
  Antipad clearances are punched around every non-matching drilled hole; matching
  power/ground holes connect directly to their plane.
- **F_Mask / B_Mask / F_Paste**: openings/stencil for all pads (vias tented).
- **Edge_Cuts**: outline + the two isolation milling slots under U9/U10.
- **PTH.drl (117 holes)** and **NPTH.drl (4x M3 Ø3.2)**.

## Isolation (spec section 7)
The two CAN channels are separated from the logic domain and from each other.
The ISO1042B transceivers and A0505S isolated DCDC converters are the only parts
that bridge the barrier; no plane copper crosses the slot/barrier gap.

## IMPORTANT - review before production
This is a programmatically generated physical layout: land patterns, pours,
vias, mask, paste and drill are real and self-consistent. Pad-to-pin **net
assignment follows the engineering spec's pin map but MUST be cross-checked
against the schematic/netlist** (IPC-356) before committing to fabrication, and
a Gerber viewer (KiCad / Gerbv / the fab's online viewer) should be used to
confirm clearances and the isolation gap for your chosen creepage rating.

Components: 92 placements, 45 routed segments.

---
Tester Present Specialist Automotive Solutions - Designed in Australia - (c) 2026 Jack Leighton.

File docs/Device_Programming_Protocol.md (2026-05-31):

# TP-CAN-2I — Device Programming Protocol (TP-DPP) v1.0

**Tester Present Specialist Automotive Solutions** · © 2026 Jack Leighton · Designed in Australia

This is the **single source of truth** for how the PC software and the device firmware talk to
each other for **reading, writing, and flashing firmware/config**. The firmware (ESP32-S3) and the
.NET 4.8.1 configurator MUST both implement this document exactly. It is transport-agnostic: the
same Application PDU rides over **CAN (via J2534 ISO-TP)**, **Serial UART**, and **USB-C CDC**.

---

## 1. Design goals

- **One command set, three transports.** Identical request/response PDUs on CAN, UART, USB-C.
- **J2534-native.** The CAN transport is ISO 15765-2 (ISO-TP), which every J2534 PassThru driver
  segments/reassembles for free — so the PC side is just `J2534Manager.SendReceive(0x7FE, pdu)`.
- **UDS-flavoured.** Service IDs mirror a subset of ISO 14229 (UDS) so the flow is familiar and
  tooling-friendly, but the ID space (0x7FE/0x7FA), DIDs, and routines are our own.
- **Safe field updates.** Firmware is written to the **inactive OTA slot**, CRC-verified, then
  activated on the next reset. A bad image never bricks the unit (rolls back to the known-good slot).

---

## 2. Transport layer

### 2.1 CAN (J2534 / ISO 15765-2)
| Item | Value |
|---|---|
| Bus | 500 kbit/s classic CAN 2.0B, 11-bit IDs |
| **Request ID (PC → device)** | **0x7FE** (PC *transmits* on 0x7FE) |
| **Response ID (device → PC)** | **0x7FA** (PC *receives* on 0x7FA) |
| Addressing | ISO-TP normal addressing, FRAME_PAD (pad to 8 bytes, 0xAA) |
| Max PDU | 4095 bytes (ISO-TP limit); we cap blocks well under this (§6) |
| Which bus | Firmware listens for 0x7FE on **CAN1 (vehicle/upstream)** by default; also
selectable on CAN2 via config DID `0x0103`. |

> From the PC's point of view this is exactly **"RX 0x7FA / TX 0x7FE"**. On the J2534 side, open
> ISO15765 @ 500k and install a flow-control filter with `txId=0x7FE, rxId=0x7FA`, then use the
> existing `J2534Manager.SendReceive(0x7FE, pdu)` — ISO-TP multiframe is handled by the adapter.

### 2.2 Serial UART  &  2.3 USB-C CDC
Both use the **same framing** (USB-C is the ESP32-S3 native USB CDC virtual COM port; UART is the
harness service lines pins 10/11/12 or service header J3).

| Item | Value |
|---|---|
| UART baud | 921600, 8N1, no flow control (USB-CDC baud is irrelevant/ignored) |
| Frame | `MAGIC(2) | LEN(2) | PDU(LEN) | CRC16(2)` |
| MAGIC | `0x54 0x50` (`"TP"`) |
| LEN | big-endian, length of PDU only (0…4095) |
| CRC16 | CRC-16/CCITT-FALSE (poly 0x1021, init 0xFFFF), big-endian, computed over **MAGIC+LEN+PDU** |
| Resync | On CRC mismatch the receiver slides forward one byte and re-scans for MAGIC. |

No byte-stuffing is used; the length + CRC + magic resync keep the stream self-correcting.

---

## 3. Application PDU (transport-agnostic)

```
Request : [ SID ] [ param bytes … ]
Positive: [ SID + 0x40 ] [ data bytes … ]
Negative: [ 0x7F ] [ SID ] [ NRC ]
```

Multi-byte fields are **big-endian**. The PDU is the payload of the CAN ISO-TP message *or* the
`PDU` field of a serial frame — never both wrapped together.

---

## 4. Service catalog

| SID | Name | Request params | Positive response |
|---|---|---|---|
| 0x10 | SESSION_CONTROL | `subfn` (01=default, 02=programming) | `subfn` + `P2(2)` + `P2*(2)` ms |
| 0x11 | ECU_RESET | `subfn` (01=hardReset, 03=jumpToApp) | `subfn` |
| 0x27 | SECURITY_ACCESS | `01`=requestSeed → / `02`=sendKey+key(4) | seed(4) / (empty) |
| 0x3E | TESTER_PRESENT | `00` | `00` |
| 0x22 | READ_DATA_BY_ID | `DID(2)` | `DID(2)` + data |
| 0x2E | WRITE_DATA_BY_ID | `DID(2)` + data | `DID(2)` |
| 0x23 | READ_MEMORY | `addr(4)` + `len(2)` | data (`len` bytes, len ≤ 1024) |
| 0x31 | ROUTINE_CONTROL | `01`=start `routineId(2)` [+opt] | `01` + `routineId(2)` + `status(1)` [+result] |
| 0x34 | REQUEST_DOWNLOAD | `fmt(1)` `alfid(1)` `addr(4)` `size(4)` `crc32(4)` | `lenFmt(1)` + `maxBlock(2)` |
| 0x36 | TRANSFER_DATA | `bsc(1)` + data | `bsc(1)` |
| 0x37 | REQUEST_TRANSFER_EXIT | (none) | `status(1)` |

`SECURITY_ACCESS` is **optional** (compile flag `DPP_SECURITY`). Default bench build is open
(seed returns 0, any key accepted) so it never blocks development; production may enable a real
seed/key. `fmt`/`alfid` follow UDS convention; for us `fmt=0x00`, `alfid=0x44` (4-byte addr + 4-byte size).

### 4.1 Data Identifiers (DIDs, for 0x22 / 0x2E)
| DID | R/W | Meaning |
|---|---|---|
| 0xF180 | R | Bootloader/protocol version (ASCII, e.g. `TP-DPP 1.0`) |
| 0xF181 | R | Application firmware version (ASCII semver + build date) |
| 0xF18A | R | Device serial number (12 bytes) |
| 0xF190 | R | Chip ID / Wi-Fi MAC (6 bytes) |
| 0xF1A0 | R | Partition map: `running(1) slotA_size(4) slotB_size(4) appUsed(4)` |
| 0xF1B0 | R | Active/running OTA slot (0 or 1) |
| 0x0100 | R/W | Device config blob (CAN bitrates, MITM mode, name) — see §8 |
| 0x0103 | R/W | Programming-bus select: 0=CAN1, 1=CAN2 |

### 4.2 Routines (for 0x31, sub 0x01 = startRoutine)
| routineId | Meaning | Extra req | status |
|---|---|---|---|
| 0xFF01 | Erase inactive OTA slot | — | 0x00 ok / 0x01 busy / 0x02 fail |
| 0xFF02 | Verify staged image CRC32 | `crc32(4)` (expected) | 0x00 match / 0x03 mismatch |
| 0xFF03 | Activate staged image (set boot + mark valid) | — | 0x00 ok |
| 0x0202 | Self-test (CAN1/CAN2 loopback, isolation rails) | — | bitmask result(1) |

---

## 5. Negative Response Codes (NRC)
| NRC | Meaning |
|---|---|
| 0x10 | generalReject |
| 0x11 | serviceNotSupported |
| 0x13 | incorrectMessageLengthOrInvalidFormat |
| 0x22 | conditionsNotCorrect (e.g. not in programming session) |
| 0x24 | requestSequenceError (e.g. TRANSFER_DATA before REQUEST_DOWNLOAD) |
| 0x31 | requestOutOfRange (addr/len/DID) |
| 0x35 | invalidKey (security) |
| 0x72 | programmingFailure (flash write/erase error) |
| 0x73 | wrongBlockSequenceCounter |
| 0x78 | responsePending (firmware busy; PC waits up to P2*) |

---

## 6. Canonical flashing sequence (write/update firmware)

The PC turns a firmware image (`.bin`, or `.hex`→bin) into this exchange:

1. `10 02` — enter **programming session** (resp gives P2/P2* timing).
2. `27 01` → seed; `27 02 <key>` — security (no-op on open builds).
3. `31 01 FF01` — **erase** inactive OTA slot (firmware replies `78` responsePending then `00`).
4. `34 00 44 <addr=00000000> <size> <crc32>` — **request download**; device replies `maxBlock`
   (e.g. 0x0200 = 512). `addr=0` means "the inactive OTA slot".
5. Loop **`36 <bsc> <chunk>`** with `chunk ≤ maxBlock`, `bsc` = 1,2,3…wrapping 0xFF→0x00. Device
   echoes `bsc`. (Firmware streams each chunk straight into `esp_ota_write`.)
6. `37` — **request transfer exit** (device finalises the OTA write).
7. `31 01 FF02 <crc32>` — **verify** staged image CRC32 (must match what was sent in step 4).
8. `31 01 FF03` — **activate** (set boot partition, mark OTA valid).
9. `11 01` — **hard reset**; unit reboots into the new image. If the new image fails to confirm
   itself healthy, the ESP32 rolls back to the previous slot automatically.

Progress % = bytes sent / total size. PC keeps the session alive with `3E 00` if a step approaches P2*.

## 6b. Reading firmware / config

- **Read identity:** `22 F181` (app version), `22 F18A` (serial), `22 F1A0` (partition map).
- **Read memory/flash region:** `23 <addr(4)> <len(2)>` in ≤1024-byte windows; PC concatenates.
  (Used to dump the running app slot for backup before an update.)
- **Read config:** `22 0100`; **write config:** `2E 0100 <blob>` (no reflash needed).

---

## 7. Timing
| Param | Value | Use |
|---|---|---|
| P2 | 50 ms | normal request→response |
| P2* | 5000 ms | extended (erase/write/verify), signalled by NRC 0x78 |
| S3 (tester present) | send `3E 00` every 2000 ms while a programming session is open |
| Inter-block | none required; device flow-controls via ISO-TP / serial CRC-NAK |

---

## 8. Device config blob (DID 0x0100) layout
```
offset  size  field
0       1     version (=1)
1       1     mitm_mode      0=passthru 1=filter 2=rewrite 3=block
2       4     can1_bitrate   (bit/s, e.g. 500000)
6       4     can2_bitrate
10      1     can_fd_enable  bit0=CAN1 FD, bit1=CAN2 FD
11      4     can_fd_data_bitrate
15      1     term1_enable   on-board 120R CAN1 (0/1)
16      1     term2_enable   on-board 120R CAN2 (0/1)
17      16    device_name    ASCII, null-padded
33      2     crc16          CRC-16/CCITT over bytes 0..32
```

---

## 9. Worked examples

**CAN (bytes on the wire are ISO-TP-segmented by the adapter; PDUs shown logically):**
```
PC → 0x7FE : 10 02                      enter programming session
dev→ 0x7FA : 50 02 00 32 13 88          P2=50ms P2*=5000ms
PC → 0x7FE : 34 00 44 00 00 00 00 00 01 00 00 1A 2B 3C 4D   download 64 KiB, crc 0x1A2B3C4D
dev→ 0x7FA : 74 02 02 00                 maxBlock = 0x0200 (512)
PC → 0x7FE : 36 01 <512 bytes>          first block
dev→ 0x7FA : 76 01
...                                      (repeat, bsc++)
PC → 0x7FE : 37                          transfer exit
dev→ 0x7FA : 77 00
PC → 0x7FE : 31 01 FF02 1A 2B 3C 4D      verify crc
dev→ 0x7FA : 71 01 FF02 00               match
PC → 0x7FE : 31 01 FF03                  activate
dev→ 0x7FA : 71 01 FF03 00
PC → 0x7FE : 11 01                       reset → boots new image
dev→ 0x7FA : 51 01
```

**Serial/USB-CDC** wraps each identical PDU as `54 50 | LEN | PDU | CRC16`. Example `3E 00`:
```
54 50 00 02 3E 00 <crc16>
```

---

## 10. Versioning
The protocol version is read via `22 F180`. Minor additions (new DIDs/routines) keep `1.x`;
breaking changes bump the major. Firmware and PC software both advertise their supported version
in their About/identity strings.
```

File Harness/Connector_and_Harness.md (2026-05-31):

# TP-CAN-2I — Heavy-Duty Connector & Wiring Harness

**Model:** TP-CAN-2I Programmable Dual-CAN Inline Interface · **Rev A**
© 2026 Jack Leighton — Tester Present Specialist Automotive Solutions · Designed in Australia

This document specifies the sealed automotive connector on the device, the internal board
interface, the device-side service harness, and the recommended in-vehicle (inline / pass-through)
deployment. It is written so a harness shop can build it and an installer can fit it.

---

## 1. Connector System Overview

The device presents **one sealed 12-way Deutsch DT receptacle** on the +X end wall. A single
mating plug carries everything the device needs: wide-range power, ignition sense, **both isolated
CAN buses**, and the **UART service link**.

```
            DEVICE (sealed enclosure)                         FIELD HARNESS
   ┌───────────────────────────────────┐
   │  PCB                               │        DT04-12PA            DT06-12SA
   │  ┌──────────┐   internal pigtail   │        receptacle          plug (mates)
   │  │ J2 Molex │ 12× size-16  ┌───────┴──┐    (pins, device)      (sockets, harness)
   │  │ Micro-Fit│══════════════│ bulkhead │◄════════╗
   │  │ 3.0 12ck │   150 mm      │ DT recep │         ║  ──► Power branch (FUSED)
   │  └──────────┘              └───────┬──┘         ║  ──► Vehicle branch  (CAN1)
   │                                    │            ║  ──► ECU branch      (CAN2)
   └───────────────────────────────────┘            ║  ──► UART service pigtail
                                                  trunk ~300 mm
```

Two-stage interface — **the same approach a production ECU uses**:

| Stage | Part | Why |
|---|---|---|
| **External** (case wall ↔ field harness) | Deutsch **DT 12-way**, sealed IP67 | Rugged, vibration-proof, glove-friendly, industry standard for off-road/truck/marine |
| **Internal** (case wall ↔ PCB) | Molex **Micro-Fit 3.0 12-ckt** + short pigtail | Lets the lid/PCB be serviced without disturbing the sealed bulkhead; polarised, latched |

> The DT family is a *wire-to-wire* system; it has no PCB-mount variant by design. Bridging it to
> the board with a short internal pigtail to a Micro-Fit header is the correct, field-proven pattern
> and keeps the IP67 bulkhead seal independent of board service.

---

## 2. Device-Side Connector — Deutsch DT 12-Way (Bill of Material)

All parts TE Connectivity / Deutsch. Quantities are **per device** unless noted.

| Item | TE / Deutsch P/N | Qty | Notes |
|---|---|---|---|
| Receptacle, 12-way, **A**-key (holds **pins**) | **DT04-12PA** | 1 | Mounts in case wall; device side |
| Wedgelock for receptacle | **W12P** | 1 | Secondary lock for DT04-12PA |
| Solid **pin** contacts, size 16 (nickel) | **0460-202-16141** | 12 | 16–20 AWG, 13 A; gold = 0460-202-1631 |
| Cavity sealing plugs (size 16) | **0413-204-1605** | as needed | Fill any unused cavity to keep IP67 |
| **Mating** plug, 12-way, A-key (holds **sockets**) | **DT06-12SA** | 1 | Harness side |
| Wedgelock for plug | **W12S** | 1 | Secondary lock for DT06-12SA |
| Solid **socket** contacts, size 16 (nickel) | **0462-201-16141** | 12 | 16–20 AWG; gold = 0462-201-1631 |

**Tooling**
- Crimp (size-16 solid contacts): Deutsch **HDT-48-00** hand crimper (or equivalent 4-indent).
- Contact removal: size-16 release tool **0411-336-1605**.
- Wedgelock seating: by hand until it clicks; never force past the lock tabs.

**Keying.** Both halves specified **A-key** so the harness can only seat one way and will not
mate with another DT-12 on the vehicle. If the same vehicle already runs DT-12 connectors, order
the device with **B** or **C** key (factory option) to prevent cross-mating.

---

## 3. Bulkhead Mounting (case wall)

The enclosure (`/Enclosure/TP-CAN-2I_enclosure.scad`) provides the matching cutout and bolt
pattern on the +X wall:

- Aperture: **25.0 mm (Y) × 21.0 mm (Z)**, lower edge **+6 mm above the inner floor**.
- Two flange screws: **M3, 31.0 mm spacing (Y)**, centred on the aperture.

Retain the DT04-12PA by clamping its rear shoulder to the inside wall with a **1.5 mm stainless
retention plate** (laser-cut, bolt pattern above) — this is a fabricated part the case shop makes
from the enclosure drawing. The receptacle's integral interfacial seal + the wall face give the
IP67 line; add a thin smear of dielectric grease on the seal at assembly. (TE's snap-in panel
clip may be substituted if the wall is left at nominal 3 mm.)

---

## 4. Internal Board Interface — Molex Micro-Fit 3.0 (12-circuit)

| Item | Molex P/N | Qty | Notes |
|---|---|---|---|
| PCB header, dual-row 12-ckt, 3.00 mm | **0430451200** (43045-1200) | 1 | Ref **J2**, on PCB |
| Crimp receptacle housing, 12-ckt | **0430251200** (43025-1200) | 1 | On internal pigtail |
| Female crimp terminals (20–24 AWG) | **0430300007** (43030-0007) | 12 | Gold; tin = 43030-0001 |

**Internal pigtail.** 12 leads, **150 mm**, size-16 *solid pin* contacts on the bulkhead end
(into DT04-12PA) and Micro-Fit terminals on the J2 end. Use **20 AWG TXL** for all 12 internal
leads (fits both contact systems; the run is short so power loss is negligible). Dress the pigtail
with a service loop so the lid lifts ~40 mm without strain.

---

## 5. Master Pinout (12-way) — applies to DT, the pigtail, and J2

Pin numbering follows the **DT04-12PA cavity map** (stamped on the receptacle face). The internal
pigtail maps DT cavity *n* → J2 pin *n* one-to-one.

| Pin | Signal | Domain | Direction | Wire (field harness) | Colour |
|---:|---|---|---|---|---|
| 1 | **+VBAT** (9–32 V) | Power | IN | 16 AWG | Red |
| 2 | **GND** (power return) | Power | — | 16 AWG | Black |
| 3 | **IGN / WAKE** (switched +12 V sense) | Power | IN | 20 AWG | Pink |
| 4 | **CAN1_H** (vehicle bus) | CAN1 ISO | bidir | 18 AWG, twisted w/ 5 | Yellow |
| 5 | **CAN1_L** (vehicle bus) | CAN1 ISO | bidir | 18 AWG, twisted w/ 4 | Green |
| 6 | **CAN1_GND / shield** | CAN1 ISO | — | 20 AWG drain | Bare/Blk-Wht |
| 7 | **CAN2_H** (ECU bus) | CAN2 ISO | bidir | 18 AWG, twisted w/ 8 | Wht/Yellow |
| 8 | **CAN2_L** (ECU bus) | CAN2 ISO | bidir | 18 AWG, twisted w/ 7 | Wht/Green |
| 9 | **CAN2_GND / shield** | CAN2 ISO | — | 20 AWG drain | Bare/Blk-Wht |
| 10 | **UART_TX** (device → host) | Logic | OUT | 20 AWG | Blue |
| 11 | **UART_RX** (host → device) | Logic | IN | 20 AWG | Orange |
| 12 | **UART_GND** | Logic | — | 20 AWG | Brown |

> **Isolation note.** Pins 4–6 (CAN1) and 7–9 (CAN2) are **galvanically isolated** from each other
> and from logic/power inside the device. *Do not bond* CAN1_GND, CAN2_GND, UART_GND, or power GND
> together anywhere in the harness — each ground stays with its own twisted set. Joining them
> defeats the isolation barrier that protects the vehicle and ECU.

---

## 6. Wire Specification

- **Power (1,2):** 16 AWG TXL/GXL automotive, 105 °C. Carries device draw (≤0.6 A typ.) plus margin.
- **Ignition (3):** 20 AWG TXL. High-impedance sense input; current is negligible.
- **CAN pairs (4/5, 7/8):** 18 AWG, **120 Ω shielded twisted pair**, ~33–40 twists/m. Keep each pair
  twisted to within 30 mm of the contact. Drain wire (6, 9) bonded to the foil shield **at the
  device end only** (avoid ground loops).
- **UART (10,11,12):** 20 AWG; run as a loose triad. Optional foil shield for noisy installs,
  drained to UART_GND at the device end.
- All contacts are **size-16 (16–20 AWG range)** — every wire above is inside that window.

---

## 7. Field Harness Construction (device-side trunk + branches)

The supplied harness is a **Y (fan-out)**: one DT06-12SA plug on a ~300 mm trunk, breaking out to
four branches. Trunk and branches run in **Ø10 mm split convoluted tubing**, taped at the breakout.

```
  DT06-12SA ──┬─[POWER]──── 7.5 A ATO fuse ── Red 16AWG ──► Battery + (ring, M6)
   (to device)│            └─────────────────  Black 16AWG ─► Chassis GND (ring, M6)
              │            └─ Pink 20AWG ─────────────────► Switched-IGN tap
              │
              ├─[VEHICLE / CAN1]── STP ─► Vehicle bus  (app-specific term., built to order)
              │
              ├─[ECU / CAN2]────── STP ─► ECU/module   (app-specific term., built to order)
              │
              └─[SERVICE / UART]── triad ─► sealed 4-way service connector (capped when unused)
```

**Build steps**
1. Cut trunk leads to length; maintain CAN twist all the way into the breakout.
2. Strip 5–6 mm; crimp size-16 **sockets** (0462-201-16141) with HDT-48-00. Inspect: insulation in
   the rear barrel, conductor visible in the inspection hole, no stray strands.
3. Insert each contact into its DT06-12SA cavity per §5 until it clicks (gentle tug test). Seat the
   **W12S** wedgelock; it will not seat fully if any contact is short — that's the built-in check.
4. Fill unused cavities (if a reduced build) with **0413-204-1605** plugs.
5. **Power branch:** inline **7.5 A** ATO fuse within 150 mm of the battery ring. Heat-shrink all
   joints with **adhesive-lined** tubing. IGN to a switched +12 V source that is dead with the key off.
6. **CAN branches:** keep shields isolated from chassis at the vehicle/ECU end; drain only at the device.
7. **Service branch:** terminate in a small sealed connector (e.g. 4-way DT or AMP Superseal) for
   UART_TX/RX/GND + a spare; fit the cap when not in use to preserve sealing.
8. Strain-relieve the trunk to the device with the DT plug's own latch; add a P-clip within 100 mm.
9. Label each branch (POWER / VEHICLE-CAN1 / ECU-CAN2 / SERVICE).

---

## 8. Recommended Deployment — true inline (pass-through)

The device is a **man-in-the-middle**: it sits *between the vehicle harness and the ECU* so it can
monitor, pass, filter, or rewrite traffic. The cleanest fit does **not cut** vehicle wiring:

```
   VEHICLE HARNESS ──►│ Vehicle branch (CAN1) │  TP-CAN-2I  │ ECU branch (CAN2) │──► ECU / MODULE
   (existing plug)     mates vehicle-side conn               mates ECU-side conn
```

- **Vehicle branch (CAN1)** is built with the **mating half of the vehicle's existing ECU
  connector**, so the vehicle harness that *used* to plug into the ECU now plugs into the device.
- **ECU branch (CAN2)** is built with **the ECU's own connector type**, so the device plugs into
  the ECU in the harness's place.
- Result: the device is electrically in series on the bus, fully isolated each side, and removable
  by unplugging two connectors — no splicing, factory-reversible.

Because vehicle/ECU connectors differ per platform, **those two end terminations are built to order**
per application. Provide the harness shop with the vehicle and ECU connector P/Ns; the device-side
trunk in §7 is fixed and never changes.

**Bus termination.** Each CAN channel has an on-board, firmware-selectable **120 Ω split
termination** (see `/Hardware/Schematic_Design.md` and `/Hardware/Fabrication_Notes.md`). When the
device replaces an end-of-bus node, enable termination on that channel; when it taps mid-bus, leave
it disabled. **The harness adds no termination resistors.**

---

## 9. Continuity / Acceptance Test (every harness)

Before shipping, verify on the assembled trunk (DT06-12SA, contacts seated, wedgelock home):

| Check | Method | Pass |
|---|---|---|
| Pin-out 1:1 | DMM continuity, DT pin *n* → branch lead *n* | < 0.3 Ω each |
| No adjacent shorts | DMM, every pin to its neighbours | > 20 MΩ |
| CAN pair integrity | 4↔5 and 7↔8 not shorted; twist intact | > 20 MΩ, visual |
| Ground isolation | 2 ↔ 6 ↔ 9 ↔ 12 mutually open | > 20 MΩ (proves isolation kept) |
| Fuse present & rated | Visual, power branch | 7.5 A ATO |
| Wedgelocks seated | Visual + tug each contact | No back-out |
| Seal integrity | DT plug fully latched; service cap fitted | Click + visual |

Record results on the build traveller. A failed **ground-isolation** check is a reject — it means a
return wire was cross-bonded and the device's isolation would be defeated.

---

## 10. Quick-Reference Card (laminate for installers)

```
TP-CAN-2I  DT-12 PINOUT          POWER: Pin1 +VBAT(9-32V)  Pin2 GND  Pin3 IGN
 1 +VBAT  2 GND   3 IGN          CAN1 (VEHICLE): Pin4 H  Pin5 L  Pin6 shield
 4 CAN1H  5 CAN1L 6 CAN1GND      CAN2 (ECU):     Pin7 H  Pin8 L  Pin9 shield
 7 CAN2H  8 CAN2L 9 CAN2GND      UART (SERVICE): Pin10 TX Pin11 RX Pin12 GND
10 TX    11 RX   12 GND          FUSE 7.5A ATO · NEVER bond the four grounds together
```

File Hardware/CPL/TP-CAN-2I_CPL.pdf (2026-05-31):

NOTE: Centroids are nominal from the mechanical placement guide; regenerate from the routed KiCad board for production pick-and-place. | Page 1

# TESTER PRESENT — TP-CAN-2I Programmable Dual-CAN Inline Interface

## Component Placement List (CPL) — Rev A

Date: 2026-06-01 | © 2026 Jack Leighton — Designed in Australia
Designator | Value | Package | MidX_mm | MidY_mm | Rotation_deg | Layer
U6 | ESP32-S3-WROOM-1-N16R8 | RF_Module:ESP32-S3-WROOM-1 | 24.000 | 20.000 | 0 | Top
U7 | MCP2518FD | Package_SO:SOIC-14_3.9x8.7mm_P1.27mm | 44.000 | 13.000 | 0 | Top
U8 | MCP2518FD | Package_SO:SOIC-14_3.9x8.7mm_P1.27mm | 44.000 | 31.000 | 0 | Top
U9 | ISO1042BDWVR | Package_SO:SOIC-8_5.3x5.3mm_P1.27mm | 58.000 | 12.000 | 0 | Top
U10 | ISO1042BDWVR | Package_SO:SOIC-8_5.3x5.3mm_P1.27mm | 58.000 | 33.000 | 0 | Top
U1 | TPS54360B-Q1 | Package_SO:HSOP-8-1EP_3.9x4.9mm_P1.27mm | 14.000 | 40.000 | 0 | Top
U2 | TLV62569 | Package_TO_SOT_SMD:SOT-23-6 | 30.000 | 42.000 | 0 | Top
U3 | A0505S-1WR3 | Converter_DCDC:Converter_DCDC_MORNSUN_A_SIP | 51.000 | 6.500 | 0 | Top
U4 | A0505S-1WR3 | Converter_DCDC:Converter_DCDC_MORNSUN_A_SIP | 51.000 | 43.000 | 0 | Top
U5 | LM66100 | Package_TO_SOT_SMD:SOT-363_SC-70-6 | TBD | TBD | 0 | Top
U11 | LM74700-Q1 | Package_TO_SOT_SMD:SOT-23-6 | TBD | TBD | 0 | Top
Q1 | CSD18532Q5B | Package_DFN_QFN:Texas_SON-8_5x6mm | TBD | TBD | 0 | Top
D1 | USBLC6-2SC6 | Package_TO_SOT_SMD:SOT-23-6 | TBD | TBD | 0 | Top
D2 | SMCJ33A | Diode_SMD:D_SMC | TBD | TBD | 0 | Top
D3 | PESD2CAN | Package_TO_SOT_SMD:SOT-23 | TBD | TBD | 0 | Top
D4 | PESD2CAN | Package_TO_SOT_SMD:SOT-23 | TBD | TBD | 0 | Top
D5 | SMAJ5.0A | Diode_SMD:D_SMA | TBD | TBD | 0 | Top
D6 | SS34 | Diode_SMD:D_SMA | TBD | TBD | 0 | Top
Y1 | 40MHz | Oscillator:Oscillator_SMD_Abracon_ASE-4Pin_3.2x2.5mm | 44.000 | 22.000 | 0 | Top
F1 | 3A 250V | Fuse:Fuse_Schurter_UMT-250 | TBD | TBD | 0 | Top
L1 | 4.7uH | Inductor_SMD:L_Bourns-SRP1245A | TBD | TBD | 0 | Top
L2 | 22uH | Inductor_SMD:L_Wurth_WE-PD-7345 | TBD | TBD | 0 | Top

NOTE: Centroids are nominal from the mechanical placement guide; regenerate from the routed KiCad board for production pick-and-place. | Page 2
Designator | Value | Package | MidX_mm | MidY_mm | Rotation_deg | Layer
L3 | 2.2uH | Inductor_SMD:L_Wurth_WE-MAPI_3015 | TBD | TBD | 0 | Top
J1 | USB-C | Connector_USB:USB_C_Receptacle_GCT_USB4105-GF-A | 4.000 | 25.000 | 0 | Top
J2 | Micro-Fit 12ckt | Connector_Molex:Molex_Micro-Fit-3.0_2x06 | 40.000 | 46.000 | 0 | Top
J3 | 1x4 2.54 | Connector_PinHeader_2.54mm:PinHeader_1x04_P2.54mm_Vertical | 24.000 | 35.000 | 0 | Top
J4 | 1x3 2.54 | Connector_PinHeader_2.54mm:PinHeader_1x03_P2.54mm_Vertical | TBD | TBD | 0 | Top
J5 | 1x3 2.54 | Connector_PinHeader_2.54mm:PinHeader_1x03_P2.54mm_Vertical | TBD | TBD | 0 | Top
SW1 | Tactile | Button_Switch_SMD:SW_SPST_PTS645 | 12.000 | 7.000 | 0 | Top
SW2 | Tactile | Button_Switch_SMD:SW_SPST_PTS645 | 12.000 | 13.000 | 0 | Top
CMC1 | CAN CMC | Inductor_SMD:L_TDK_ACT45B | 64.500 | 12.000 | 0 | Top
CMC2 | CAN CMC | Inductor_SMD:L_TDK_ACT45B | 64.500 | 33.000 | 0 | Top
LED1 | Green | LED_SMD:LED_0603_1608Metric | TBD | TBD | 0 | Top
LED2 | Blue | LED_SMD:LED_0603_1608Metric | TBD | TBD | 0 | Top
LED3 | Amber | LED_SMD:LED_0603_1608Metric | TBD | TBD | 0 | Top
LED4 | Amber | LED_SMD:LED_0603_1608Metric | TBD | TBD | 0 | Top
LED5 | Blue | LED_SMD:LED_0603_1608Metric | TBD | TBD | 0 | Top
R1 | 5.1k (x2) | Resistor_SMD:R_0402_1005Metric | TBD | TBD | 0 | Top
R2 | 100k | Resistor_SMD:R_0603_1608Metric | TBD | TBD | 0 | Top
R3 | 22k | Resistor_SMD:R_0603_1608Metric | TBD | TBD | 0 | Top
R4 | 1k (x5) | Resistor_SMD:R_0603_1608Metric | TBD | TBD | 0 | Top
R5 | 10k (x2) | Resistor_SMD:R_0603_1608Metric | TBD | TBD | 0 | Top
R6 | 10k (x2) | Resistor_SMD:R_0603_1608Metric | TBD | TBD | 0 | Top
R7 | 60R (x4) | Resistor_SMD:R_0603_1608Metric | TBD | TBD | 0 | Top
R8 | 120R (x2) | Resistor_SMD:R_0603_1608Metric | TBD | TBD | 0 | Top
R9 | 52.3k | Resistor_SMD:R_0603_1608Metric | TBD | TBD | 0 | Top
R10 | 10k | Resistor_SMD:R_0603_1608Metric | TBD | TBD | 0 | Top

NOTE: Centroids are nominal from the mechanical placement guide; regenerate from the routed KiCad board for production pick-and-place. | Page 3
Designator | Value | Package | MidX_mm | MidY_mm | Rotation_deg | Layer
R11 | 182k | Resistor_SMD:R_0603_1608Metric | TBD | TBD | 0 | Top
R12 | 499k | Resistor_SMD:R_0603_1608Metric | TBD | TBD | 0 | Top
R13 | 75k | Resistor_SMD:R_0603_1608Metric | TBD | TBD | 0 | Top
R14 | 540k | Resistor_SMD:R_0603_1608Metric | TBD | TBD | 0 | Top
R15 | 120k | Resistor_SMD:R_0603_1608Metric | TBD | TBD | 0 | Top
C1 | 100uF 50V | Capacitor_SMD:CP_Elec_10x10.5 | TBD | TBD | 0 | Top
C2 | 10uF 50V (x2) | Capacitor_SMD:C_1210_3225Metric | TBD | TBD | 0 | Top
C3 | 4.7uF 50V | Capacitor_SMD:C_1206_3216Metric | TBD | TBD | 0 | Top
C4 | 47uF 16V | Capacitor_SMD:C_1210_3225Metric | TBD | TBD | 0 | Top
C5 | 22uF 10V | Capacitor_SMD:C_0805_2012Metric | TBD | TBD | 0 | Top
C6 | 2.2nF | Capacitor_SMD:C_0402_1005Metric | TBD | TBD | 0 | Top
C7 | 100nF 50V (x4) | Capacitor_SMD:C_0603_1608Metric | TBD | TBD | 0 | Top
C8 | 100nF (x12) | Capacitor_SMD:C_0402_1005Metric | TBD | TBD | 0 | Top
C9 | 10uF 25V (x2) | Capacitor_SMD:C_0805_2012Metric | TBD | TBD | 0 | Top
C10 | 4.7uF 16V | Capacitor_SMD:C_0603_1608Metric | TBD | TBD | 0 | Top
C11 | 18pF (x2) | Capacitor_SMD:C_0402_1005Metric | TBD | TBD | 0 | Top

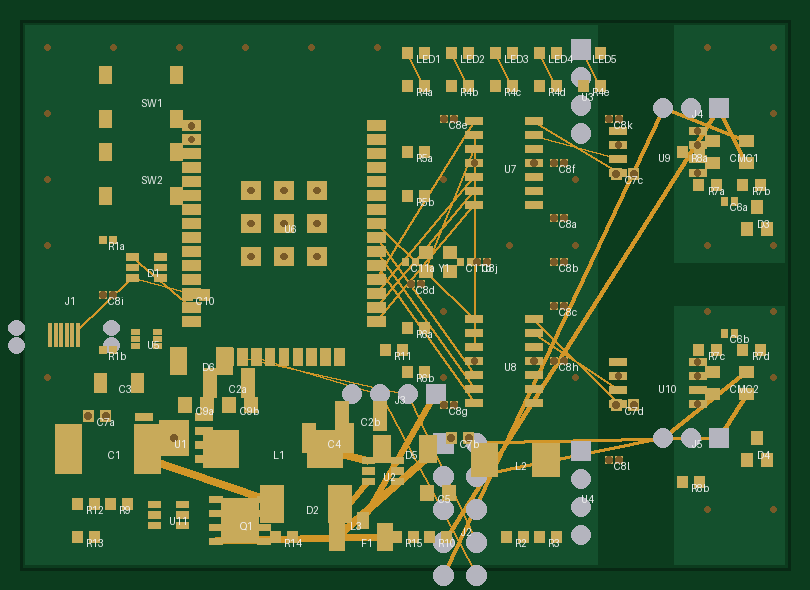
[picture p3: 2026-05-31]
Hardware/Gerbers/preview_top.png

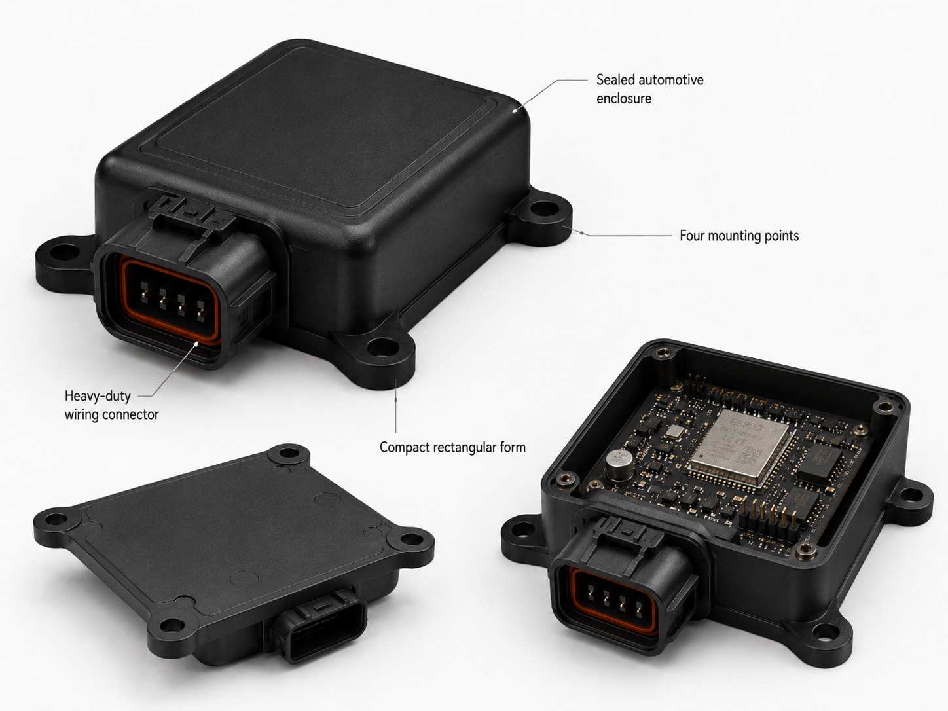
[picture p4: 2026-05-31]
Images/60717bd0-7fa3-4d9c-abab-d6c3a3cc39e0.png

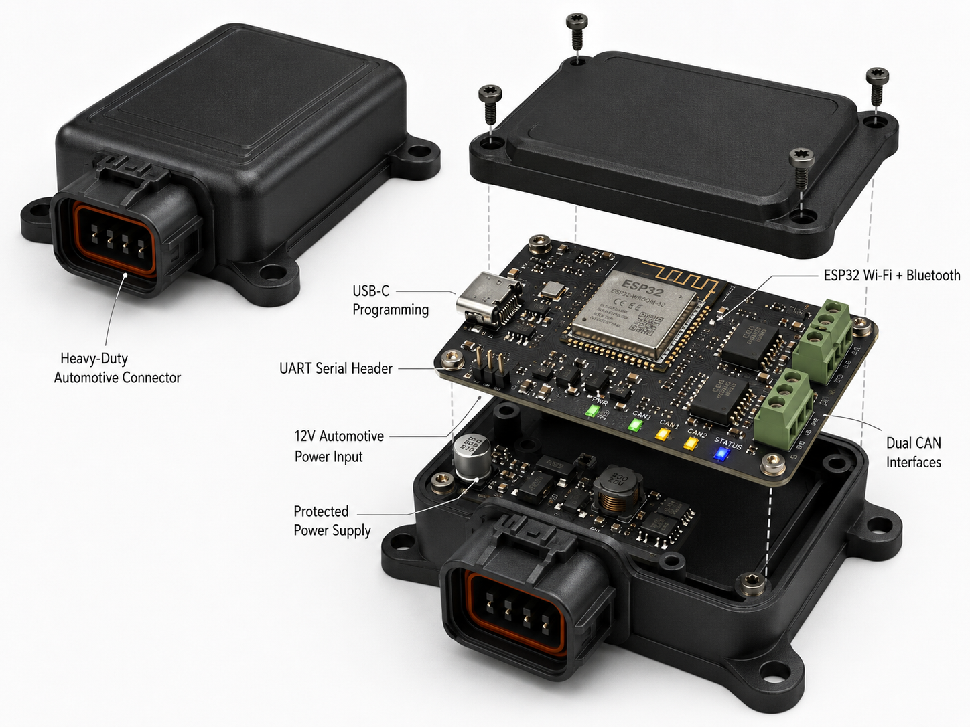
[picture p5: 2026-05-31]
Images/125dcbcd-4566-4c65-9275-549c772c395c.png

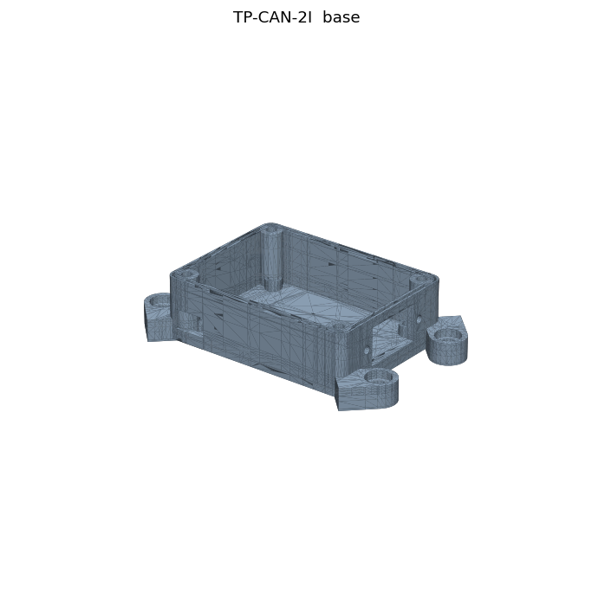
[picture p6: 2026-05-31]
Enclosure/STL/preview_base.png

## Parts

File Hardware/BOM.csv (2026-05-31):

Ref | Qty | Value | MPN | Manufacturer | Footprint | Domain | Description
U6 | 1 | ESP32-S3-WROOM-1-N16R8 | ESP32-S3-WROOM-1-N16R8 | Espressif | RF_Module:ESP32-S3-WROOM-1 | Logic | MCU module dual-core LX7 Wi-Fi/BLE 16MB flash 8MB PSRAM
U7 | 1 | MCP2518FD | MCP2518FDT-H/SL | Microchip | Package_SO:SOIC-14_3.9x8.7mm_P1.27mm | Logic | CAN FD SPI controller channel 1
U8 | 1 | MCP2518FD | MCP2518FDT-H/SL | Microchip | Package_SO:SOIC-14_3.9x8.7mm_P1.27mm | Logic | CAN FD SPI controller channel 2
U9 | 1 | ISO1042BDWVR | ISO1042BDWVR | Texas Instruments | Package_SO:SOIC-8_5.3x5.3mm_P1.27mm | Iso1 | Isolated CAN FD transceiver ch1 +/-70V bus fault 5kVrms
U10 | 1 | ISO1042BDWVR | ISO1042BDWVR | Texas Instruments | Package_SO:SOIC-8_5.3x5.3mm_P1.27mm | Iso2 | Isolated CAN FD transceiver ch2 +/-70V bus fault 5kVrms
U1 | 1 | TPS54360B-Q1 | TPS54360BQDDARQ1 | Texas Instruments | Package_SO:HSOP-8-1EP_3.9x4.9mm_P1.27mm | Power | Wide-Vin 60V 3.5A buck pre-regulator to 5V
U2 | 1 | TLV62569 | TLV62569DBVR | Texas Instruments | Package_TO_SOT_SMD:SOT-23-6 | Power | 5V to 3.3V 2A synchronous buck (logic rail)
U3 | 1 | A0505S-1WR3 | A0505S-1WR3 | MORNSUN | Converter_DCDC:Converter_DCDC_MORNSUN_A_SIP | Iso1 | Isolated 5V-5V 1W DCDC for CAN1 bus supply
U4 | 1 | A0505S-1WR3 | A0505S-1WR3 | MORNSUN | Converter_DCDC:Converter_DCDC_MORNSUN_A_SIP | Iso2 | Isolated 5V-5V 1W DCDC for CAN2 bus supply
U5 | 1 | LM66100 | LM66100DCKR | Texas Instruments | Package_TO_SOT_SMD:SOT-363_SC-70-6 | Power | Ideal-diode load switch USB 5V power-path OR
U11 | 1 | LM74700-Q1 | LM74700QDBVRQ1 | Texas Instruments | Package_TO_SOT_SMD:SOT-23-6 | Power | Ideal-diode controller reverse-polarity protection
Q1 | 1 | CSD18532Q5B | CSD18532Q5B | Texas Instruments | Package_DFN_QFN:Texas_SON-8_5x6mm | Power | 60V N-channel MOSFET reverse-polarity pass device
D1 | 1 | USBLC6-2SC6 | USBLC6-2SC6 | STMicroelectronics | Package_TO_SOT_SMD:SOT-23-6 | Logic | USB D+/D- ESD protection array
D2 | 1 | SMCJ33A | SMCJ33A | Littelfuse | Diode_SMD:D_SMC | Power | 1500W TVS unidirectional 33V standoff (load-dump clamp)
D3 | 1 | PESD2CAN | PESD2CAN215 | Nexperia | Package_TO_SOT_SMD:SOT-23 | Iso1 | CAN bus ESD/TVS protection ch1
D4 | 1 | PESD2CAN | PESD2CAN215 | Nexperia | Package_TO_SOT_SMD:SOT-23 | Iso2 | CAN bus ESD/TVS protection ch2
D5 | 1 | SMAJ5.0A | SMAJ5.0A | Littelfuse | Diode_SMD:D_SMA | Power | 5V rail TVS clamp
D6 | 1 | SS34 | SS34 | Vishay | Diode_SMD:D_SMA | Power | Schottky catch/freewheel (buck) 40V 3A
Y1 | 1 | 40MHz | ASEM1-40.000MHZ-LC-T | Abracon | Oscillator:Oscillator_SMD_Abracon_ASE-4Pin_3.2x2.5mm | Logic | 40MHz CMOS oscillator for MCP2518FD (CLKO daisy-chain)
F1 | 1 | 3A 250V | 3403.0167.22 | Schurter | Fuse:Fuse_Schurter_UMT-250 | Power | SMD fuse 3A 250V fast (fault isolation)
L1 | 1 | 4.7uH | 74279228 | Wurth Elektronik | Inductor_SMD:L_Bourns-SRP1245A | Power | Input pi-filter inductor
L2 | 1 | 22uH | 74437529203221 | Wurth Elektronik | Inductor_SMD:L_Wurth_WE-PD-7345 | Power | Buck inductor 22uH 3A (TPS54360)
L3 | 1 | 2.2uH | 74438335022 | Wurth Elektronik | Inductor_SMD:L_Wurth_WE-MAPI_3015 | Power | Buck inductor 2.2uH (TLV62569)
J1 | 1 | USB-C | USB4105-GF-A | GCT | Connector_USB:USB_C_Receptacle_GCT_USB4105-GF-A | Logic | USB-C 2.0 receptacle 16P SMD with through-hole tabs
J2 | 1 | Micro-Fit 12ckt | 0430451200 | Molex | Connector_Molex:Molex_Micro-Fit-3.0_2x06 | Logic | Internal board header 12-circuit to harness loom
J3 | 1 | 1x4 2.54 | 61300411121 | Wurth Elektronik | Connector_PinHeader_2.54mm:PinHeader_1x04_P2.54mm_Vertical | Logic | UART service header TX/RX/GND/3V3
J4 | 1 | 1x3 2.54 | 61300311121 | Wurth Elektronik | Connector_PinHeader_2.54mm:PinHeader_1x03_P2.54mm_Vertical | Iso1 | CAN1 termination select jumper (120R)
J5 | 1 | 1x3 2.54 | 61300311121 | Wurth Elektronik | Connector_PinHeader_2.54mm:PinHeader_1x03_P2.54mm_Vertical | Iso2 | CAN2 termination select jumper (120R)
SW1 | 1 | Tactile | PTS645SL50SMTR92 | C&K | Button_Switch_SMD:SW_SPST_PTS645 | Logic | BOOT button (GPIO0)
SW2 | 1 | Tactile | PTS645SL50SMTR92 | C&K | Button_Switch_SMD:SW_SPST_PTS645 | Logic | RESET button (EN)
CMC1 | 1 | CAN CMC | ACT45B-510-2P-TL003 | TDK | Inductor_SMD:L_TDK_ACT45B | Iso1 | CAN1 common-mode choke 51uH
CMC2 | 1 | CAN CMC | ACT45B-510-2P-TL003 | TDK | Inductor_SMD:L_TDK_ACT45B | Iso2 | CAN2 common-mode choke 51uH
LED1 | 1 | Green | 150060VS75000 | Wurth Elektronik | LED_SMD:LED_0603_1608Metric | Logic | PWR LED green
LED2 | 1 | Blue | 150060BS75000 | Wurth Elektronik | LED_SMD:LED_0603_1608Metric | Logic | Wi-Fi LED blue
LED3 | 1 | Amber | 150060AS75000 | Wurth Elektronik | LED_SMD:LED_0603_1608Metric | Logic | CAN1 activity LED amber
LED4 | 1 | Amber | 150060AS75000 | Wurth Elektronik | LED_SMD:LED_0603_1608Metric | Logic | CAN2 activity LED amber
LED5 | 1 | Blue | 150060BS75000 | Wurth Elektronik | LED_SMD:LED_0603_1608Metric | Logic | STATUS LED blue
R1 | 2 | 5.1k | RC0402FR-075K1L | Yageo | Resistor_SMD:R_0402_1005Metric | Logic | USB-C CC1/CC2 pull-down (5.1k each)
R2 | 1 | 100k | RC0603FR-07100KL | Yageo | Resistor_SMD:R_0603_1608Metric | Power | Ignition divider top
R3 | 1 | 22k | RC0603FR-0722KL | Yageo | Resistor_SMD:R_0603_1608Metric | Power | Ignition divider bottom
R4 | 5 | 1k | RC0603FR-071KL | Yageo | Resistor_SMD:R_0603_1608Metric | Logic | LED series resistors
R5 | 2 | 10k | RC0603FR-0710KL | Yageo | Resistor_SMD:R_0603_1608Metric | Logic | BOOT/EN pull-ups
R6 | 2 | 10k | RC0603FR-0710KL | Yageo | Resistor_SMD:R_0603_1608Metric | Logic | MCP2518FD CS pull-ups
R7 | 4 | 60R | RC0603FR-0760RL | Yageo | Resistor_SMD:R_0603_1608Metric | Iso | CAN split-termination 60R (2 per channel)
R8 | 2 | 120R | RC0603FR-07120RL | Yageo | Resistor_SMD:R_0603_1608Metric | Iso | CAN selectable 120R termination
R9 | 1 | 52.3k | RC0603FR-0752K3L | Yageo | Resistor_SMD:R_0603_1608Metric | Power | TPS54360 feedback top (5V set with R10=10k Vref0.8V)
R10 | 1 | 10k | RC0603FR-0710KL | Yageo | Resistor_SMD:R_0603_1608Metric | Power | TPS54360 feedback bottom
R11 | 1 | 182k | RC0603FR-07182KL | Yageo | Resistor_SMD:R_0603_1608Metric | Power | TPS54360 RT timing (~500kHz)
R12 | 1 | 499k | RC0603FR-07499KL | Yageo | Resistor_SMD:R_0603_1608Metric | Power | TPS54360 EN UVLO top
R13 | 1 | 75k | RC0603FR-0775KL | Yageo | Resistor_SMD:R_0603_1608Metric | Power | TPS54360 EN UVLO bottom
R14 | 1 | 540k | RC0603FR-07540KL | Yageo | Resistor_SMD:R_0603_1608Metric | Power | TLV62569 feedback top (3.3V set with R15=120k Vref0.6V)
R15 | 1 | 120k | RC0603FR-07120KL | Yageo | Resistor_SMD:R_0603_1608Metric | Power | TLV62569 feedback bottom
C1 | 1 | 100uF 50V | EEH-ZC1H101P | Panasonic | Capacitor_SMD:CP_Elec_10x10.5 | Power | Input bulk electrolytic (polymer hybrid)
C2 | 2 | 10uF 50V | CGA6P3X7R1H106K250AB | TDK | Capacitor_SMD:C_1210_3225Metric | Power | Input ceramic decoupling 50V X7R
C3 | 1 | 4.7uF 50V | CGA5L1X7R1H475K160AC | TDK | Capacitor_SMD:C_1206_3216Metric | Power | Buck bootstrap/input
C4 | 1 | 47uF 16V | GRM32ER61C476KE15L | Murata | Capacitor_SMD:C_1210_3225Metric | Power | 5V rail bulk
C5 | 1 | 22uF 10V | GRM21BR61A226ME51L | Murata | Capacitor_SMD:C_0805_2012Metric | Power | 3.3V rail bulk
C6 | 1 | 2.2nF | CGA2B2C0G1H222J050BA | TDK | Capacitor_SMD:C_0402_1005Metric | Power | TPS54360 bootstrap/slow-start
C7 | 4 | 100nF 50V | CGA3E2X7R1H104K080AA | TDK | Capacitor_SMD:C_0603_1608Metric | Iso | CAN split-termination cap 4.7nF / decoupling
C8 | 12 | 100nF | CGA3E2X7R1H104K080AA | TDK | Capacitor_SMD:C_0402_1005Metric | Logic | IC decoupling 100nF (ESP32/MCP/ISO/regulators)
C9 | 2 | 10uF 25V | GRM21BR61E106KA73L | Murata | Capacitor_SMD:C_0805_2012Metric | Iso | Isolated 5V output bulk (per ISO1042)
C10 | 1 | 4.7uF 16V | GRM188R61C475KAAJD | Murata | Capacitor_SMD:C_0603_1608Metric | Logic | ESP32 module bulk decoupling
C11 | 2 | 18pF | CGA2B2C0G1H180J050BA | TDK | Capacitor_SMD:C_0402_1005Metric | Logic | Oscillator load caps (if crystal variant)
PCB | 1 | PCB 4-layer | TP-CAN-2I-PCB | TesterPresent |  | Mechanical | 4-layer FR-4 1.6mm ENIG black soldermask white silk

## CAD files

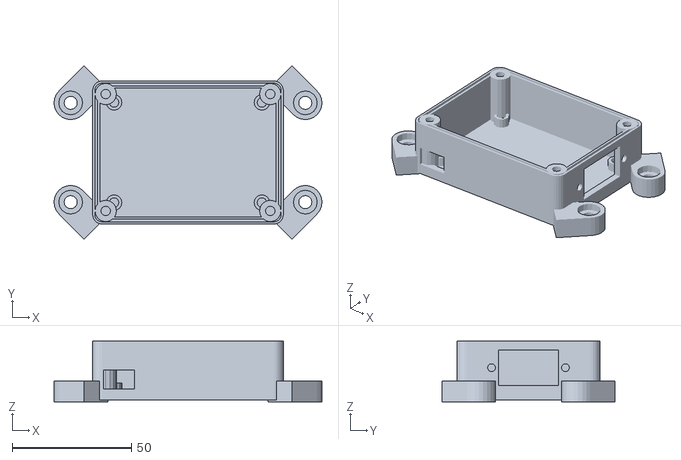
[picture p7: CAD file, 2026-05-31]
Enclosure/STL/TP-CAN-2I_base.stl
112.4 x 72.7 x 25.4

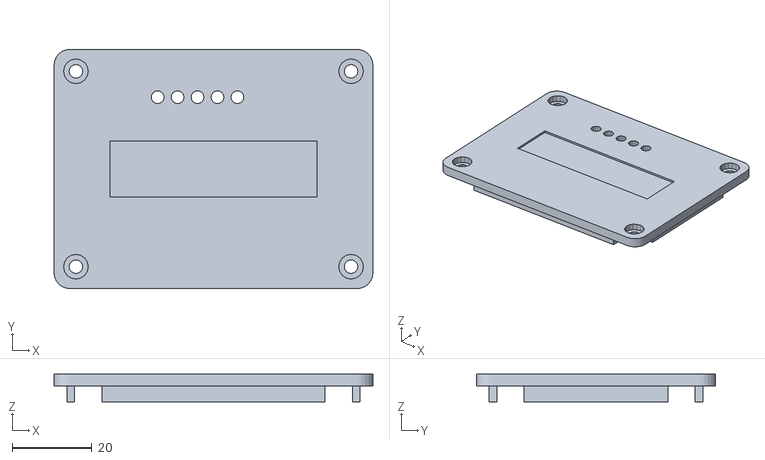
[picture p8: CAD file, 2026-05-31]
Enclosure/STL/TP-CAN-2I_lid.stl
80.0 x 60.0 x 7.00

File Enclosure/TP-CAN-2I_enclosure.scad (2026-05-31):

// ============================================================================
//  Tester Present  TP-CAN-2I  -- Rugged Sealed Enclosure (parametric)
//  (c) 2026 Jack Leighton - Designed in Australia
//
//  Two-part automotive enclosure for the Programmable Dual-CAN Inline Interface.
//  Base tray + lid, perimeter gasket seal (IP65 target), four heavy-duty corner
//  mounting ears (M5 + steel eyelet), Deutsch DT-12 bulkhead cutout, sealed USB-C
//  service port, PCB standoffs (M3 brass inserts), and 5 LED light-pipes.
//
//  RENDER / EXPORT (OpenSCAD):
//    set  part = "base"  | "lid" | "assembly" | "print"
//    F6 (render) then  File > Export > STL.  Export base and lid separately for SLA.
//  Units: millimetres.
//
//  MANUFACTURING MASTER:  the print-ready, validated 2-manifold meshes in
//  ./STL/TP-CAN-2I_base.stl and ./STL/TP-CAN-2I_lid.stl are produced by the
//  pure-Python builder ./build_enclosure.py (no OpenSCAD required) and are the
//  authoritative parts for the case manufacturer.  This .scad is a parametric
//  reference for editing/visualisation; its seal cross-section is modelled
//  slightly differently but the external envelope and all features match.
// ============================================================================

part = "assembly";          // "base" | "lid" | "assembly" | "print"
$fn = 64;

// ---- PCB -------------------------------------------------------------------
pcb_x      = 70;            // PCB length  (matches KiCad board)
pcb_y      = 50;            // PCB width
pcb_t      = 1.6;
pcb_clear  = 2.0;           // gap PCB edge -> inner wall
pcb_hole_inset = 4.0;       // PCB mounting-hole inset (matches generate_board.py)

// ---- Shell -----------------------------------------------------------------
wall       = 3.0;           // side-wall thickness (rugged)
floor_t    = 3.0;           // base floor thickness
lid_top_t  = 3.0;           // lid top thickness
corner_r   = 4.0;           // outer vertical corner radius
standoff_h = 4.0;           // PCB sits this high above the floor
head_room  = 16.0;          // clearance above PCB top for tall parts (DCDC, caps)
gasket_w   = 1.6;           // gasket groove width
gasket_d   = 1.4;           // gasket groove depth
lid_lip_h  = 4.0;           // lid tongue depth into the seal
fit_gap    = 0.20;          // assembly clearance

// ---- Derived inner / outer -------------------------------------------------
inner_x = pcb_x + 2*pcb_clear;            // 74
inner_y = pcb_y + 2*pcb_clear;            // 54
outer_x = inner_x + 2*wall;               // 80
outer_y = inner_y + 2*wall;               // 60
cavity_h = standoff_h + pcb_t + head_room; // 21.6
base_h  = floor_t + cavity_h;             // 24.6  (rim height)

// PCB origin inside the cavity (case coords, lower-left of inner cavity = (wall,wall))
pcb_ox = wall + pcb_clear;                // 5
pcb_oy = wall + pcb_clear;                // 5

// PCB mounting-hole centres (case coords)
pcb_holes = [
  [pcb_ox + pcb_hole_inset,         pcb_oy + pcb_hole_inset],
  [pcb_ox + pcb_x - pcb_hole_inset, pcb_oy + pcb_hole_inset],
  [pcb_ox + pcb_hole_inset,         pcb_oy + pcb_y - pcb_hole_inset],
  [pcb_ox + pcb_x - pcb_hole_inset, pcb_oy + pcb_y - pcb_hole_inset],
];

// ---- Fasteners / inserts ---------------------------------------------------
m3_insert_d = 4.0;          // heat-set brass insert pilot (M3)
m3_clear_d  = 3.4;          // M3 screw clearance
m3_head_d   = 6.2;          // M3 cap-head counterbore
m5_clear_d  = 5.5;          // M5 vehicle-mount clearance
eyelet_od   = 10.0;         // steel eyelet outer (anti-crush)

// ---- Corner lid-screw towers (inside, outboard of seal) --------------------
tower_d   = 9.0;
// tower centres tucked into the four outer corners
tw = outer_x/2 - corner_r - 1.0;
th = outer_y/2 - corner_r - 1.0;
tower_pos = [ [corner_r+1.5, corner_r+1.5],
              [outer_x-corner_r-1.5, corner_r+1.5],
              [corner_r+1.5, outer_y-corner_r-1.5],
              [outer_x-corner_r-1.5, outer_y-corner_r-1.5] ];

// ---- Connector (Deutsch DT-12 flange receptacle) ---------------------------
//  Bulkhead cutout on the +X end wall.  VERIFY against the exact DT04-12PA
//  flange-receptacle drawing before tooling.
conn_w   = 25.0;            // cutout width  (Y)
conn_h   = 15.0;            // cutout height (Z) - sized to fit under the rim
conn_z   = floor_t + 3.0;   // cutout bottom above floor
conn_flange_screw = 3.3;    // DT flange mount screws
conn_flange_dx = 31.0;      // flange screw spacing (Y)

// ---- USB-C service port (sealed with rubber bung) --------------------------
usb_w = 13.0; usb_h = 8.0;
usb_x = pcb_ox + 6.0;       // aligns with J1 (USB-C) near left edge
usb_z = floor_t + standoff_h + pcb_t;   // at PCB top plane

// ---- LED light-pipes (5) in the lid ----------------------------------------
//  PCB LEDs MUST be placed to match these XY centres (case coords):
led_d = 3.2;
led_y = outer_y - 12.0;
led_xs = [26, 31, 36, 41, 46];   // PWR, Wi-Fi, CAN1, CAN2, STATUS

// ============================================================================
//  Helpers
// ============================================================================
module rbox(x, y, z, r) {           // prism with vertical rounded edges
  hull() for (sx=[r, x-r], sy=[r, y-r]) translate([sx, sy, 0]) cylinder(h=z, r=r);
}

module corner_ear(p, ang) {         // heavy-duty mounting ear with eyelet
  ear_len = 13.0; ear_t = 8.0; ear_w = 14.0;
  translate(p) rotate([0,0,ang]) {
    difference() {
      union() {
        // tab
        hull() {
          cylinder(h=ear_t, d=eyelet_od+3);
          translate([ear_len,0,0]) cylinder(h=ear_t, d=ear_w);
        }
      }
      // M5 hole through the outer end + eyelet pocket
      translate([ear_len,0,-1]) cylinder(h=ear_t+2, d=m5_clear_d);
      translate([ear_len,0,ear_t-2.5]) cylinder(h=3, d=eyelet_od);   // eyelet flush pocket
    }
  }
}

// ============================================================================
//  BASE
// ============================================================================
module base() {
  difference() {
    union() {
      // outer shell
      rbox(outer_x, outer_y, base_h, corner_r);
      // mounting ears (diagonal from each corner)
      corner_ear([0,0],            225);
      corner_ear([outer_x,0],      315);
      corner_ear([0,outer_y],      135);
      corner_ear([outer_x,outer_y], 45);
    }
    // hollow cavity
    translate([wall, wall, floor_t])
      rbox(inner_x, inner_y, base_h, max(0.5, corner_r-wall));
    // gasket groove in the top rim (proper channel of width gasket_w: outer ring - inner ring)
    translate([0,0,base_h-gasket_d])
      difference() {
        translate([wall*0.5, wall*0.5, 0])
          rbox(outer_x-wall, outer_y-wall, gasket_d+1, corner_r-0.5);
        translate([wall*0.5+gasket_w, wall*0.5+gasket_w, -1])
          rbox(outer_x-wall-2*gasket_w, outer_y-wall-2*gasket_w, gasket_d+3, corner_r-1);
      }
    // connector cutout on +X end wall
    translate([outer_x-wall-1, outer_y/2-conn_w/2, conn_z])
      cube([wall+2, conn_w, conn_h]);
    for (s=[-1,1]) translate([outer_x-wall-1, outer_y/2 + s*conn_flange_dx/2, conn_z+conn_h/2])
      rotate([0,90,0]) cylinder(h=wall+2, d=conn_flange_screw);
    // USB-C service port on -Y side wall
    translate([usb_x-usb_w/2, -1, usb_z-usb_h/2]) cube([usb_w, wall+2, usb_h]);
  }

  // PCB standoffs (inside)
  for (p=pcb_holes) translate([p[0], p[1], floor_t])
    difference() {
      cylinder(h=standoff_h, d=6.5);
      translate([0,0,-0.5]) cylinder(h=standoff_h+1, d=m3_insert_d);
    }

  // lid-screw towers (inside the corners, up to rim)
  for (p=tower_pos) translate([p[0], p[1], floor_t])
    difference() {
      cylinder(h=cavity_h-gasket_d, d=tower_d);
      translate([0,0,cavity_h-gasket_d-6]) cylinder(h=7, d=m3_insert_d);
    }
}
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

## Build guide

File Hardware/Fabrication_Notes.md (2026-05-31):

# TP-CAN-2I — PCB Fabrication & Assembly Notes

## 1. Board Summary
| Item | Value |
|---|---|
| Size | 70.0 × 50.0 mm, 3 mm corner radius |
| Layers | 4 (signal / GND / PWR / signal) |
| Thickness | 1.6 mm |
| Material | FR-4, Tg ≥ 150 °C (automotive temp) |
| Copper | 1 oz outer, 0.5 oz inner (1 oz inner if budget allows) |
| Finish | ENIG (gold, for fine-pitch ESP32 + ISO parts) |
| Soldermask | Matte black |
| Silkscreen | White |
| Min track/space | 0.2 mm / 0.2 mm (design uses ≥0.25 mm) |
| Min drill | 0.3 mm |
| Mounting holes | 4 × Ø3.2 mm NPTH (M3) |
| Special | 2 × routed isolation slots; board-edge antenna keep-out |

## 2. Stackup (target — confirm with fab)
```
 L1  F.Cu      35 µm   signal + components (top)
     prepreg  ~0.21 mm
 L2  In1.Cu    17 µm   GND plane  (continuous reference)
     core     ~1.065 mm
 L3  In2.Cu    17 µm   PWR plane  (+3V3 / +5V pours)
     prepreg  ~0.21 mm
 L4  B.Cu      35 µm   signal + ground pour (bottom)
 Total ≈ 1.6 mm
```
Controlled impedance is not required (CAN is low-speed differential, well below the need
for tight Zdiff), but keep CAN H/L as a tightly-coupled pair with matched length.

## 3. Net Classes / Design Rules
Defined in `TP-CAN-2I.kicad_pro` and `TP-CAN-2I.kicad_dru`:
| Class | Clearance | Track | Use |
|---|---|---|---|
| Default | 0.20 mm | 0.25 mm | signals |
| Power | 0.30 mm | 0.60 mm | VBAT/+5V/+3V3 |
| CAN_LOGIC | 0.25 mm | 0.30 mm | controller↔isolator TXD/RXD |
| CAN1_ISO | 0.30 mm | 0.40 mm | vehicle bus (isolated domain 1) |
| CAN2_ISO | 0.30 mm | 0.40 mm | ECU bus (isolated domain 2) |

**Isolation rule (`.kicad_dru`):** ≥ **4 mm** creepage between each `*_ISO` domain and every
other domain (logic and the other bus). The two milled slots under U9/U10 increase creepage
locally. Do **not** pour copper, place vias, or route traces across the barrier.

## 4. Layer Routing Plan
- **L1 (F.Cu):** components + short signal routing; CAN diff pairs; SPI bus.
- **L2 (GND):** solid ground plane. Split only where the isolation barrier crosses — the
  isolated bus domains get their **own** local ground pours (GND_ISO1, GND_ISO2) on L1/L4,
  NOT connected to L2 GND except through ISO parts.
- **L3 (PWR):** +3V3 pour (logic 2/3) and +5V pour; isolated +5V_ISOn pours are local islands
  near each transceiver only.
- **L4 (B.Cu):** ground pour + overflow routing; keep CAN pairs together if routed here.
- **Antenna:** the ESP32-S3-WROOM-1 PCB-antenna end overhangs the top board edge; **no copper
  on any layer** under the keep-out (see module datasheet, ~15 × 6 mm).

## 5. Critical Layout Rules
1. Place 100 nF decoupling at every IC VDD pin, vias straight to plane.
2. ESP32-S3: bulk 4.7 µF + 100 nF close; thermal vias under module GND pad.
3. TPS54360 buck: tight hot loop (VIN cap → SW → catch diode → GND); keep SW node small;
   FB trace away from SW/inductor; thermal pad → GND with via array.
4. CAN: H/L tightly coupled; common-mode choke close to connector; split-termination + TVS
   right at the bus entry; isolated ground pour referenced to each transceiver's GND2.
5. Each isolated DC-DC (A0505S): keep primary/secondary copper separated under the slot/keepout.
6. USB-C: D± as 90 Ω diff pair, short, ESD diode (USBLC6) at the connector.

## 6. Fabrication Output Checklist (export from KiCad once routed)
- [ ] Gerber X2 (all copper, mask, silk, paste, Edge.Cuts) — `/Hardware/Production`
- [ ] Excellon drill (PTH + NPTH, with map)
- [ ] IPC-356 netlist (for bare-board electrical test)
- [ ] Pick-and-place (CPL) top/bottom
- [ ] BOM (`/Hardware/BOM.csv`)
- [ ] PDF assembly drawing + fab drawing (stackup, notes)
- [ ] 3D STEP (for enclosure fit-check against `/Enclosure`)

## 7. Assembly Notes
- Single-sided SMT (all parts top) to reduce cost; through-hole only for the DC-DC modules,
  pin headers, and connector if a TH variant is chosen.
- Reflow profile per ENIG + ESP32 module (Espressif reflow guideline, peak ≤ 245 °C).
- Conformal coat after test (automotive humidity/vibration) — mask the connector & USB-C.

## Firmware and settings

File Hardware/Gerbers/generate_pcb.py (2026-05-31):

#!/usr/bin/env python3
# -*- coding: utf-8 -*-
"""
TP-CAN-2I  REAL 4-layer PCB Gerber + Excellon generator
========================================================
Designed in Australia - (c) 2026 Jack Leighton -
Tester Present Specialist Automotive Solutions.

This generator produces a *real* manufacturable Gerber set with actual copper:
  * Land patterns (pads) for EVERY component in the CPL/BOM, placed at the
    engineering-spec coordinates (TBD parts auto-placed in their domain).
  * Solder-mask openings and solder-paste apertures matched to every SMD pad.
  * 4-layer copper:  F.Cu / In1.Cu(GND) / In2.Cu(PWR) / B.Cu  with copper pours
    split into three galvanic domains  (LOGIC | CAN1-ISO | CAN2-ISO)  honouring
    the isolation barrier from section 7 of the Master Engineering Specification.
  * Power-tree, SPI2 bus, CAN_H/CAN_L differential pairs and USB pair routed on
    the outer layers; ground/power return by plane + stitching vias.
  * Edge.Cuts board outline (70x50 mm, R3) with the two isolation milling slots.
  * Real Excellon drill (PTH vias + component holes) and NPTH (4x M3) files.
  * Gerber Job JSON, layer map, fab README and a zipped package.

RS-274X:  %FSLAX46Y46*%  metric, 4 integer / 6 decimal.  Coordinate frame is the
same Y-down frame used by the board outline and the CPL, so every layer self-
aligns.  All placed components are on the Top side (CPL Layer=Top).
"""

import math
import json
import zipfile
import re
from pathlib import Path

SCRIPT_DIR = Path(__file__).parent.resolve()
OUT = SCRIPT_DIR

# ----------------------------------------------------------------------------
# Board geometry  (from the spec: ~70 x 50 mm, 4-layer, isolation slots)
# ----------------------------------------------------------------------------
W, H = 70.0, 50.0          # board outline (mm)
R = 3.0                    # corner radius
EDGE_CLR = 0.5             # copper pull-back from board edge / slots

MH = [(4.0, 4.0), (66.0, 4.0), (4.0, 46.0), (66.0, 46.0)]  # M3 NPTH centres
MH_D = 3.2

# Isolation milling slots (Edge.Cuts) under the two ISO1042B transceivers.
SLOTS = [(57.3, 8.5, 58.7, 15.5), (57.3, 29.5, 58.7, 36.5)]

# Vertical galvanic-isolation barrier: x >= BARRIER_X is the isolated bus side.
BARRIER_X = 54.0
# Horizontal split between CAN1 (upper) and CAN2 (lower) isolated domains.
CHAN_SPLIT_Y = 24.0

SCALE = 1_000_000          # mm -> 4.6 integer

def ci(v):                 # mm -> integer gerber coordinate
    return int(round(v * SCALE))

def XY(x, y):
    return "X%dY%d" % (ci(x), ci(y))

# ----------------------------------------------------------------------------
# Aperture manager - de-duplicates aperture definitions per layer and assigns
# D-codes starting at 10.  Supports circle/rect/obround + a rounded-rect macro.
# ----------------------------------------------------------------------------
class Apertures:
    def __init__(self):
        self.defs = []          # ordered list of (dcode, gerber-def-string)
        self.bykey = {}         # key -> dcode
        self.next = 10
        self.macros = {}        # name -> body, emitted once

    def _add(self, key, body):
        if key in self.bykey:
            return self.bykey[key]
        d = self.next
        self.next += 1
        self.bykey[key] = d
        self.defs.append((d, body))
        return d

    def circle(self, dia):
        return self._add(("C", round(dia, 5)), "C,%.5f" % dia)

    def rect(self, w, h):
        return self._add(("R", round(w, 5), round(h, 5)), "R,%.5fX%.5f" % (w, h))

    def obround(self, w, h):
        return self._add(("O", round(w, 5), round(h, 5)), "O,%.5fX%.5f" % (w, h))

    def roundrect(self, w, h, r):
        # Use an obround when fully rounded, else a rect with rounded corners via
        # a simple aperture macro (chamfer-free rounded rectangle).
        r = min(r, w / 2.0, h / 2.0)
        if r <= 0:
            return self.rect(w, h)
        if abs(r - min(w, h) / 2.0) < 1e-6:
            return self.obround(w, h)
        # rounded-rect macro: a filled rect + two obrounds is overkill; emit a
        # macro outline (8-point) approximating the rounded rectangle.
        mname = "RR"
        if mname not in self.macros:
            # parametric not used; we inline concrete macros per size instead.
            pass
        key = ("RR", round(w, 5), round(h, 5), round(r, 5))
        if key in self.bykey:
            return self.bykey[key]
        # Build a concrete macro for this size from a center rect + 4 edge rects
        # + 4 corner circles (all primitives unioned).
        idx = len([k for k in self.macros]) + 1
        nm = "RR%d" % idx
        hw, hh = w / 2.0, h / 2.0
        body = []
        body.append("21,1,%.5f,%.5f,0,0,0*" % (w - 2 * r, h))      # vert center rect
        body.append("21,1,%.5f,%.5f,0,0,0*" % (w, h - 2 * r))      # horiz center rect
        for sx in (-1, 1):
            for sy in (-1, 1):
                body.append("1,1,%.5f,%.5f,%.5f*" % (2 * r, sx * (hw - r), sy * (hh - r)))
        self.macros[nm] = "%AM" + nm + "*\n" + "\n".join(body) + "%"
        d = self.next
        self.next += 1
        self.bykey[key] = d
        self.defs.append((d, nm))   # body is macro name (no params)
        return d

    def emit(self):
        out = []
        for nm, body in self.macros.items():
            out.append(body)
        for d, body in self.defs:
            out.append("%%ADD%d%s*%%" % (d, body))
        return out

# ----------------------------------------------------------------------------
# Layer accumulator - flashes (pads), draws (traces), regions (pours/cutouts).
# ----------------------------------------------------------------------------
class Layer:
    def __init__(self, file_function, polarity="Positive"):
        self.ff = file_function
        self.polarity = polarity
        self.ap = Apertures()
        self.ops = []           # list of gerber body lines (already aperture-aware)

    # -- primitives ---------------------------------------------------------
    def flash(self, dcode, x, y):
        self.ops.append(("flash", dcode, x, y))

    def draw(self, dcode, x0, y0, x1, y1):
        self.ops.append(("draw", dcode, x0, y0, x1, y1))

    def region(self, pts, dark=True):
        self.ops.append(("region", pts, dark))

    def arc_region_circle(self, cx, cy, r, dark=True):
        # approximate a disk as a 32-gon region (used for round antipads/pours)
        n = 32
        pts = [(cx + r * math.cos(2 * math.pi * k / n),
                cy + r * math.sin(2 * math.pi * k / n)) for k in range(n)]
        self.region(pts, dark)

    # -- emit ---------------------------------------------------------------
    def render(self):
        body = []
        cur = None
        cur_pol = "D"   # dark
        for op in self.ops:
            if op[0] == "flash":
                _, d, x, y = op
                if cur_pol != "D":
                    body.append("%LPD*%"); cur_pol = "D"
                if cur != d:
                    body.append("D%d*" % d); cur = d
                body.append("%sD03*" % XY(x, y))
            elif op[0] == "draw":
                _, d, x0, y0, x1, y1 = op
                if cur_pol != "D":
                    body.append("%LPD*%"); cur_pol = "D"
                if cur != d:
                    body.append("D%d*" % d); cur = d
                body.append("%sD02*" % XY(x0, y0))
                body.append("%sD01*" % XY(x1, y1))
            elif op[0] == "region":
                _, pts, dark = op
                pol = "D" if dark else "C"
                if pol != cur_pol:
                    body.append("%LPD*%" if dark else "%LPC*%")
                    cur_pol = pol
                body.append("G36*")
                x0, y0 = pts[0]
                body.append("%sD02*" % XY(x0, y0))
                for (x, y) in pts[1:]:
                    body.append("G01%sD01*" % XY(x, y))
                body.append("%sD01*" % XY(x0, y0))   # close
                body.append("G37*")
        if cur_pol == "C":
            body.append("%LPD*%")
        return body

    def to_text(self):
        hdr = [
            "%FSLAX46Y46*%",
            "%MOMM*%",
            "%TF.FileFunction," + self.ff + "*%",
            "%TF.FilePolarity," + self.polarity + "*%",
            "%TF.SameCoordinates,Original*%",
            "%TF.CreationDate,2026-06-01T00:00:00Z*%",
            "G04 TP-CAN-2I real copper - generated by generate_pcb.py*",
            "G01*",
            "G75*",
        ]
        aps = self.ap.emit()
        body = self.render()
        return "\n".join(hdr + aps + body + ["M02*"]) + "\n"

# ============================================================================
# FOOTPRINT LIBRARY
# A footprint = dict(pads=[...], body=(w,h), silk=[polylines]).
# Pad tuple: (name, dx, dy, w, h, shape, drill)   shape in R/C/O/RR ; drill=None=SMD
# Coordinates are relative to the component origin (CPL Mid X/Y), Y-down.
# ============================================================================
def _silk_box(w, h, m=0.15):
    hw, hh = w / 2.0 + m, h / 2.0 + m
    return [[(-hw, -hh), (hw, -hh), (hw, hh), (-hw, hh), (-hw, -hh)]]

def fp_chip(padw, padh, spacing, bodyw, bodyh):
    s = spacing / 2.0
    pads = [("1", -s, 0, padw, padh, "RR", None),
            ("2",  s, 0, padw, padh, "RR", None)]
    # two short silk lines above/below the body (don't cover pads)
    yh = bodyh / 2.0 + 0.18
    silk = [[(-bodyw/2, -yh), (bodyw/2, -yh)], [(-bodyw/2, yh), (bodyw/2, yh)]]
    return dict(pads=pads, body=(max(bodyw, spacing+padw), bodyh), silk=silk)

# 2-terminal chip table: padw,padh,spacing,bodyw,bodyh  (mm)
CHIP = {
    "R_0402_1005Metric": (0.60, 0.64, 0.92, 1.00, 0.50),
    "C_0402_1005Metric": (0.60, 0.64, 0.92, 1.00, 0.50),
    "R_0603_1608Metric": (0.90, 0.95, 1.60, 1.60, 0.80),
    "C_0603_1608Metric": (0.90, 0.95, 1.60, 1.60, 0.80),
    "LED_0603_1608Metric": (0.90, 0.95, 1.60, 1.60, 0.80),
    "C_0805_2012Metric": (1.15, 1.45, 1.95, 2.00, 1.25),
    "C_1206_3216Metric": (1.05, 1.80, 3.40, 3.20, 1.60),
    "C_1210_3225Metric": (1.15, 2.70, 3.40, 3.20, 2.50),
    "D_SMA": (1.50, 2.50, 4.20, 4.30, 2.60),
    "D_SMC": (2.10, 3.30, 6.20, 6.10, 3.30),
    "Fuse_Schurter_UMT-250": (1.40, 2.40, 4.40, 5.00, 3.20),
}

def fp_dual(npins, pitch, padw, padh, span, body=None, ep=None):
    """Dual-row SMD (SOIC/SOT/QFN-dual). npins total, npins/2 per side.
    Pin 1 = bottom-left, numbering up the left then down the right (CCW)."""
    per = npins // 2
    s = span / 2.0
    y0 = -(per - 1) * pitch / 2.0
    pads = []
    for i in range(per):                       # left column, bottom->top => pins 1..per upward
        y = y0 + i * pitch
        pads.append((str(i + 1), -s, -y, padw, padh, "RR", None))
    for i in range(per):                       # right column top->bottom
        y = y0 + (per - 1 - i) * pitch
        pads.append((str(per + i + 1), s, -y, padw, padh, "RR", None))
    if ep:
        pads.append(("EP", 0, 0, ep[0], ep[1], "R", None))
    bw, bh = body if body else (span - padw, per * pitch + 0.4)
    silk = _silk_box(bw, bh)
    # pin-1 dot
    silk.append([(-s - padw/2 - 0.3, y0 - 0.0)])
    return dict(pads=pads, body=(span + padw, per * pitch + padh), silk=silk)

def fp_sot23_3():
    pads = [("1", -0.95, 1.0, 1.0, 1.2, "RR", None),
            ("2",  0.95, 1.0, 1.0, 1.2, "RR", None),
            ("3",  0.00, -1.0, 1.0, 1.2, "RR", None)]
    return dict(pads=pads, body=(2.9, 2.8), silk=_silk_box(1.3, 2.4))

def fp_sip(npins, pitch, drill, pad, body):
    y0 = -(npins - 1) * pitch / 2.0
    pads = []
    for i in range(npins):
        sh = "R" if i == 0 else "C"
        pads.append((str(i + 1), 0, y0 + i * pitch, pad, pad, sh, drill))
    return dict(pads=pads, body=body, silk=_silk_box(*body))

def fp_header(npins, pitch=2.54, drill=1.0, pad=1.8):
    y0 = -(npins - 1) * pitch / 2.0
    pads = [(str(i+1), 0, y0 + i*pitch, pad, pad, ("R" if i == 0 else "C"), drill)
            for i in range(npins)]
    return dict(pads=pads, body=(2.54, npins*pitch), silk=_silk_box(2.4, npins*pitch))

def fp_microfit_2x6(pitch=3.0, drill=1.0, pad=1.8):
    pads = []
    n = 0
    xs = (-pitch/2.0, pitch/2.0)
    y0 = -(6 - 1) * pitch / 2.0
    for col, x in enumerate(xs):
        for row in range(6):
            n += 1
            y = y0 + row * pitch
            sh = "R" if n == 1 else "C"
            pads.append((str(n), x, y, pad, pad, sh, drill))
    return dict(pads=pads, body=(pitch + 4.0, 6 * pitch + 2.0),
                silk=_silk_box(pitch + 3.5, 6 * pitch + 1.0))

def fp_usbc_16():
    """GCT USB4105-GF-A 16-pin USB2.0 Type-C: 2 rows x 6 SMD signal pads at the
    front edge + 4 THT shield/mount legs."""
    pads = []
    pitch = 0.5
    # two rows of 6 pads (A and B side), front of receptacle faces +Y
    cols = [(-1.25 + k * pitch) for k in range(6)]
    for k, x in enumerate(cols):
        pads.append(("A%d" % (k+1), x, 3.2, 0.30, 1.30, "R", None))
        pads.append(("B%d" % (k+1), x, 4.0, 0.30, 1.30, "R", None))
    # 4 plated shield legs
    for (sx, sy) in [(-4.32, 3.0), (4.32, 3.0), (-4.32, 4.6), (4.32, 4.6)]:
        pads.append(("SH", sx, sy, 1.4, 1.4, "O", 0.9))
    return dict(pads=pads, body=(9.0, 3.5), silk=[[(-4.5,2.0),(4.5,2.0)],
               [(-4.5,5.2),(4.5,5.2)], [(-4.5,2.0),(-4.5,5.2)], [(4.5,2.0),(4.5,5.2)]])

def fp_osc_4():
    """4-pad SMD oscillator 3.2x2.5 (Abracon ASE)."""
    px, py = 1.1, 0.85
    pads = [("1", -px, py, 1.2, 1.1, "R", None),
            ("2",  px, py, 1.2, 1.1, "R", None),
            ("3",  px, -py, 1.2, 1.1, "R", None),
            ("4", -px, -py, 1.2, 1.1, "R", None)]
    return dict(pads=pads, body=(3.2, 2.5), silk=_silk_box(3.2, 2.5))

def fp_cmc_act45b():
    """TDK ACT45B common-mode choke: 4 terminals (2x2), 4.5x3.2 body."""
    px, py = 1.55, 1.0
    pads = [("1", -px,  py, 1.3, 1.0, "RR", None),
            ("2", -px, -py, 1.3, 1.0, "RR", None),
            ("3",  px, -py, 1.3, 1.0, "RR", None),
            ("4",  px,  py, 1.3, 1.0, "RR", None)]
    return dict(pads=pads, body=(4.5, 3.2), silk=_silk_box(4.5, 3.2))

def fp_ind2(padw, padh, spacing, body):
    s = spacing / 2.0
    pads = [("1", -s, 0, padw, padh, "RR", None), ("2", s, 0, padw, padh, "RR", None)]
    return dict(pads=pads, body=body, silk=_silk_box(*body))

def fp_elec(dia=10.0):
    pads = [("1", -3.6, 0, 2.4, 4.5, "RR", None), ("2", 3.6, 0, 2.4, 4.5, "RR", None)]
    n = 24
    ring = [(dia/2*math.cos(2*math.pi*k/n), dia/2*math.sin(2*math.pi*k/n)) for k in range(n+1)]
    return dict(pads=pads, body=(dia, dia), silk=[ring])

def fp_tactile_smd():
    """PTS645 SMD tactile: 4 gull pads."""
    px, py = 3.25, 2.0
    pads = [("1", -px,  py, 1.1, 1.6, "R", None),
            ("2",  px,  py, 1.1, 1.6, "R", None),
            ("3",  px, -py, 1.1, 1.6, "R", None),
            ("4", -px, -py, 1.1, 1.6, "R", None)]
    return dict(pads=pads, body=(6.0, 3.5), silk=_silk_box(4.5, 3.5))

def fp_esp32s3():
    """ESP32-S3-WROOM-1 land pattern: 3-sided castellated ring (pitch 1.27,
    pad 0.9x1.6 pointing outward) + central thermal/GND EP grid.
    18.0 x 25.5 module; antenna overhangs the top edge (no pads there)."""
    pads = []
    bw, bh = 18.0, 25.5
    pitch = 1.27
    pw, pl = 0.90, 1.60        # pad across / outward length
    n_side = 15                # pads down each long edge
    n_bot = 9                  # pads along bottom edge
    # outward length means pad centre sits inboard of the edge by pl/2 - overhang
    xl = -bw/2 + pl/2 - 0.2
    xr =  bw/2 - pl/2 + 0.2
    y0 = -(n_side - 1) * pitch / 2.0
    pin = 1
    for i in range(n_side):                       # LEFT, top->bottom : pins 1..15
        pads.append((str(pin), xl, y0 + i*pitch, pl, pw, "R", None)); pin += 1
    yb = bh/2 - pl/2 + 0.2
    x0 = -(n_bot - 1) * pitch / 2.0
    for i in range(n_bot):                         # BOTTOM, left->right : 16..24
        pads.append((str(pin), x0 + i*pitch, yb, pw, pl, "R", None)); pin += 1
    for i in range(n_side):                         # RIGHT, bottom->top : 25..39
        pads.append((str(pin), xr, y0 + (n_side-1-i)*pitch, pl, pw, "R", None)); pin += 1
    # central EP grid (thermal / GND) 3x3 with stitching vias added later
    for gx in (-3.0, 0.0, 3.0):
        for gy in (-3.0, 0.0, 3.0):
            pads.append(("EP", gx, gy, 1.7, 1.7, "R", None))
    silk = [[(-bw/2, -bh/2), (bw/2, -bh/2)],          # top (antenna) edge bar
            [(-bw/2, -bh/2), (-bw/2, bh/2)],
            [(bw/2, -bh/2), (bw/2, bh/2)],
            [(-bw/2, bh/2), (bw/2, bh/2)]]
    return dict(pads=pads, body=(bw, bh), silk=silk)

def get_footprint(pkg):
    p = pkg.split(":", 1)[-1]
    if p in CHIP:
        return fp_chip(*CHIP[p])
    if p == "ESP32-S3-WROOM-1":
        return fp_esp32s3()
    if p == "SOIC-14_3.9x8.7mm_P1.27mm":
        return fp_dual(14, 1.27, 1.55, 0.60, 5.40, body=(3.9, 8.7))
    if p == "SOIC-8_5.3x5.3mm_P1.27mm":
        return fp_dual(8, 1.27, 1.55, 0.60, 7.20, body=(5.3, 5.3))
    if p == "HSOP-8-1EP_3.9x4.9mm_P1.27mm":
        return fp_dual(8, 1.27, 1.55, 0.60, 5.40, body=(3.9, 4.9), ep=(2.6, 3.2))
    if p == "Texas_SON-8_5x6mm":
        return fp_dual(8, 1.27, 1.20, 0.60, 4.40, body=(5.0, 6.0), ep=(3.4, 4.0))
    if p == "SOT-23-6":
        return fp_dual(6, 0.95, 1.10, 0.60, 2.60, body=(1.6, 2.9))
    if p == "SOT-363_SC-70-6":
        return fp_dual(6, 0.65, 0.70, 0.40, 2.00, body=(1.25, 2.0))
    if p == "SOT-23":
        return fp_sot23_3()
    if p.startswith("Converter_DCDC_MORNSUN_A_SIP"):
        return fp_sip(4, 2.54, 0.9, 1.8, (6.0, 10.0))
    if p == "PinHeader_1x04_P2.54mm_Vertical":
        return fp_header(4)
    if p == "PinHeader_1x03_P2.54mm_Vertical":
        return fp_header(3)
    if p == "Molex_Micro-Fit-3.0_2x06":
        return fp_microfit_2x6()
    if p == "USB_C_Receptacle_GCT_USB4105-GF-A":
        return fp_usbc_16()
    if p.startswith("Oscillator_SMD_Abracon_ASE"):
        return fp_osc_4()
    if p == "L_TDK_ACT45B":
        return fp_cmc_act45b()
    if p == "L_Bourns-SRP1245A":
        return fp_ind2(3.2, 3.4, 9.4, (12.5, 12.5))
    if p == "L_Wurth_WE-PD_7345" or p == "L_Wurth_WE-PD-7345":
        return fp_ind2(2.4, 3.0, 5.6, (7.3, 7.3))
    if p == "L_Wurth_WE-MAPI_3015":
        return fp_ind2(1.0, 1.4, 2.4, (3.0, 3.0))
    if p == "CP_Elec_10x10.5":
        return fp_elec(10.0)
    if p == "SW_SPST_PTS645":
        return fp_tactile_smd()
    # safe generic fallback: 2-pad 0805-ish so nothing silently vanishes
    return fp_chip(1.15, 1.45, 1.95, 2.0, 1.25)

# ============================================================================
# PLACEMENT TABLE  (ref, package, x, y, rot)
# Fixed parts use the CPL/spec coordinates; TBD parts are placed into their
# correct electrical domain (power left, MCU centre, controllers mid-right,
# isolated transceivers/bus far right beyond the x=54 barrier).
# ============================================================================
PKG = {
    "ESP32": "RF_Module:ESP32-S3-WROOM-1",
    "MCP": "Package_SO:SOIC-14_3.9x8.7mm_P1.27mm",
    "ISO": "Package_SO:SOIC-8_5.3x5.3mm_P1.27mm",
    "TPS": "Package_SO:HSOP-8-1EP_3.9x4.9mm_P1.27mm",
    "TLV": "Package_TO_SOT_SMD:SOT-23-6",
    "DCDC": "Converter_DCDC:Converter_DCDC_MORNSUN_A_SIP",
    "LM66": "Package_TO_SOT_SMD:SOT-363_SC-70-6",
    "LM74": "Package_TO_SOT_SMD:SOT-23-6",
    "SON8": "Package_DFN_QFN:Texas_SON-8_5x6mm",
    "USBLC": "Package_TO_SOT_SMD:SOT-23-6",
    "SMC": "Diode_SMD:D_SMC",
    "SOT23": "Package_TO_SOT_SMD:SOT-23",
    "SMA": "Diode_SMD:D_SMA",
    "OSC": "Oscillator:Oscillator_SMD_Abracon_ASE-4Pin_3.2x2.5mm",
    "FUSE": "Fuse:Fuse_Schurter_UMT-250",
    "L_SRP": "Inductor_SMD:L_Bourns-SRP1245A",
    "L_PD": "Inductor_SMD:L_Wurth_WE-PD-7345",
    "L_MAPI": "Inductor_SMD:L_Wurth_WE-MAPI_3015",
    "USB": "Connector_USB:USB_C_Receptacle_GCT_USB4105-GF-A",
    "MFIT": "Connector_Molex:Molex_Micro-Fit-3.0_2x06",
    "H4": "Connector_PinHeader_2.54mm:PinHeader_1x04_P2.54mm_Vertical",
    "H3": "Connector_PinHeader_2.54mm:PinHeader_1x03_P2.54mm_Vertical",
    "SW": "Button_Switch_SMD:SW_SPST_PTS645",
    "CMC": "Inductor_SMD:L_TDK_ACT45B",
    "LED": "LED_SMD:LED_0603_1608Metric",
    "ELEC": "Capacitor_SMD:CP_Elec_10x10.5",
    "R04": "Resistor_SMD:R_0402_1005Metric",
    "R06": "Resistor_SMD:R_0603_1608Metric",
    "C04": "Capacitor_SMD:C_0402_1005Metric",
    "C06": "Capacitor_SMD:C_0603_1608Metric",
    "C08": "Capacitor_SMD:C_0805_2012Metric",
    "C12": "Capacitor_SMD:C_1210_3225Metric",
    "C12b": "Capacitor_SMD:C_1206_3216Metric",
}
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

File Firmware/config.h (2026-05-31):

// ////////////////////////////////////////////////////////////////////////////////////////////////////
//      Tester Present Specialist Automotive Solutions - Programmable CAN Interface - CAN/Serial/USB //
//               Copyright (c) 2026 Jack Leighton. All rights reserved.                              //
// ////////////////////////////////////////////////////////////////////////////////////////////////////
// ....................................................................................................
// ....................................DEVELOPED IN AUSTRALIA..........................................
// ....................................................................................................
// ....................................................................................................
//                                           .  ....       .            ..
//                                          .:::. .:.... ...           .=+.
//                                           .::::::::::::::.         .=++-.
//                                          .:::::::::::::..          .++++:
//                                 .:-=.   .::::::::::::::.:          :++++-
//                               .=+++++-:..:::::::::::::.  .         :+++++-=.
//                              :+++++++++:::::::::::::::::...        :++++++++.
//                           ...-+++++++++::::::::::::::::::::.  .    +++++++++:
//                         .-=.+++++++++++-:::::::::::::::::::-++:  .=+++++++++=.
//                         -++++++++++++++-:::::::::::::::::::-+++++++++++++++++-
//                        .-++++++++++++++-:::::::::::::::::::=+++++++++++++++++-
//                       .=+++++++++++++++-:::::::::::::::::::=++++++++++++++++++..
//                     .:+++++++++++++++++=:::::::::::::::::::=++++++++++++++++++++=.
//                ..-+++++++++++++++++++++=:::::::::::::::::::+++++++++++++++++++++++=.
//            .:=+++++++++++++++++++++++++=:::::::::::::::::::++++++++++++++++++++++++-
//         ..:++++++++++++++++++++++++++++=:::::::::::::::::::+++++++++++++++++++++++++.
//        :.+++++++++++++++++++++++++++++++:::::::::::::::::::+++++++++++++++++++++++++++-.
//        -++++++++++++++++++++++++++++++++.::::JAKKA351::::::+++++++++++++++++++++++++++=
//        :++++++++++++++++++++++++++++++++.::::::::::::::::::++++++++++++++++++++++++++++=.
//        -++++++++++++++++++++++++++++++++.:-------------::::======++++++++++++++++++++++++.
//        .=+++++++++++++++++++++++++++++++-+++++++++++++++++++++++=+++++++++++++++++++++++++:
//        .+-++++++++++++++++++++++++++++++-+++++++++++++++++++++++=+++++++++++++++++++++++++-
//        .:+++++++++++++++++++++++++++++++-+++++++++++++++++++++++=+++++++++++++++++++++++++:
//          .++++++++++++++++++++++++++++++-+++++++++++++++++++++++----======++++++++==++=+==:
//           .+++++++++++++++++++++++++++++=+++++++++++++++++++++++-===============-=========-.
//             =++++++++++++++++++++++++++++=++++++++++++++++++++++-=========================.
//             .++++++++++++++++++++++++++++=++==++++++++++++++++++-========================..
//              :+++++++++++++++++++++++=:.       ..:-+++++++++++++-=======================-.
//               .+++++++++++++++++=:.               .-+++++==+++++=======================-.
//               .++++++++++++++++:                    .+++:.++++++-====================-:.
//               .=++++++++:......                     .==  =:+++++=+:=================:
//              .-++++++=.                                 ..:+++++=+++:==========--=-.
//                 ..:..                                  .... .=+=+++++=----==-===--:.
//                                                              -+=+++++++++++++-==-.
//                                                              .=-+++++++++++++=:-:.
//                                                                ..:=+++++++++:::.
//                                                                    ..  .:-.
//         TESTER PRESENT SPECIALIST AUTOMOTIVE SOLUTIONS              .:.     .
//                                                                     ....   ..
//                                                                      :=====-
//                                                                      .=====:
//                                                                      .-===-.
//                                                                        ::.
//
//
// ....................................................................................................
// ....................................................................................................
// ....................................................................................................
// ....................................................................................................
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

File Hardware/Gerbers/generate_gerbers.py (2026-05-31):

#!/usr/bin/env python3
# -*- coding: utf-8 -*-
"""
TP-CAN-2I Gerber generator  (DEPRECATED ENTRYPOINT - now defers to the real one)
================================================================================
The original version of this script emitted *placeholder* copper layers (valid
RS-274X headers with no pads/traces/pours).  That is no longer acceptable: the
real, copper-complete generator lives in `generate_pcb.py` and produces actual
land patterns, 4-layer pours with the galvanic-isolation split, vias, routing,
solder mask, paste and drill.

This file is kept only so the historical command keeps working: it simply runs
`generate_pcb.py`.  Run either:

    python generate_pcb.py        # preferred
    python generate_gerbers.py    # same result, via this shim

(c) 2026 Jack Leighton - Tester Present Specialist Automotive Solutions.
"""
import runpy
from pathlib import Path

if __name__ == "__main__":
    target = Path(__file__).with_name("generate_pcb.py")
    print("[generate_gerbers.py] deprecated -> running %s" % target.name)
    runpy.run_path(str(target), run_name="__main__")
